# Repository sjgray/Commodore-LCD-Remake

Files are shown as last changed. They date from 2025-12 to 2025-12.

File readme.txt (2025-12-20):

CLCD Re-Make Project  by Steve Gray		cbmsteve.ca
====================  and Mike Naberezny        mikenaberezny.com

The goal of this project is to remake/recreate the never released
Commodore LCD computer. Only a few working prototypes were ever
made. These were almost production ready and luckily a few survived
and information about them was released. Thanks go to Jeff Porter
and Bil Herd for helping with this project. Since the LCD computer
was never produced there are no spare parts and no way to replace
them. Several things are no longer available, such as the custom
chips, keyboard, case and LCD Panel, so we must recreate them or
adapt the design to use modern replacements and similar available parts.

Please see the webpage for more info: http://www.cbmsteve.ca/clcd/index.html

*** This is a work in progress!!! The project is currently incomplete.
    Files are provided for information only. Do not attempt to build
    it unless you are willing to debug and fix things. I will not be
    able to support you. As this is a personal project I can not say
    if or when this might be fully functional!

*** GERBER files have not been provided. They may be made available when
    the project is in a more stable/working state.

DESIGN
======

Schematics
----------

Bil Herd had saved all 4 original pages of the CLCD schematics however
one was misplaced. The 3 pages were sent to Mike, scanned in high-res,
and returned to Bil. Later Bil eventually found the missing page and took
several photos. I (Steve) stitched them together into one photo and used
it as a guide for recreating the missing page.

Design Changes
--------------

Since the custom chips and other parts of the computer were not available
I decided to use a CPLD for the MMU/glue and the C128's VDC chip for the
video. A 32K Dual-port RAM was used for the main memory. Both the CPU and
VDC can access this memory independently/simultaneously and the CPU can
write to it directly without the need to go through the VDC registers. This
means writing to the (text) screen works like the original machine. Only
a small patch is needed for the KERNAL.

Western Design Center still makes 6502-series chips and these were used in
the new design. The original 65C102 CPU was replaced with a 65C02 which is
fully compatible. Similarly equivalent WDC IO chips were also available but
in a smaller PLCC package.

Everything is powered by a simple 12V supply.

LCD Panel/Video
---------------

The original 80x16 (480x128 pixel) monochrome LCD panel was replaced by a
modern widescreen colour panel of roughly the same size. It includes a
controller board with HDMI and composite video inputs. We will use the HDMI
input for best quality. The VDC's RGBI output will be converted to HDMI
using an RGB2HDMI converter. There is an RGBI output connector for an
external display.

Keyboard
--------

Two keyboards were designed with MX switches. One design is like the
original keyboard and uses the diamond arrow cursor. The other design uses
an inverted-T cursor. This design was chosen so that normal keycaps
could be used. Included are files to create custom printed keycaps from
maxkeyboard.com. Custom 3D printed keycaps that match the original, including
the diamond cursor, are in progress for the next revision.

EPROM-PLA
---------

The V1 board initially required the EPROM-PLA board, which plugged into the
expansion connector. This board used an EPROM to emulate a PLA that did
decoding for basic functionality. It is no longer required as it has been
replaced by Mike's CPLD implementation.

Case
----

I have designed a case that can be 3D printed. I used Light-beige PLA.
It must be assembled from multiple pieces and requires brass screw inserts
to hold it together. The initial case is an approximation and has been
designed to accommodate the new LCD panel and it's controller and the
RGB2HDMI adapter. All ports are on the back.

Missing Features
----------------

The battery/power, modem, and barcode port features were not implemented in
the initial design but can hopefully be added later as the design progresses.

V1 PROTO
========

V1 is the first prototype that was developed and demonstrated to Jeff Porter
and Bil Herd.

The first prototype PCB was produced but it requires multiple fixes to
correct errors. These were done by Mike. Mike also did further disassembly of
the CLCD KERNAL to be able to re-assemble it back to an original binary and
then patch it to get the VDC working. He also added serial IO for debug purposes.
Mike wrote the CPLD code that functions like a programmed logic array (PLA) to
map in the 32K RAM, KERNAL ROM and IO. The machine is able to boot.

The MMU has not been implemented yet, so the machine can only boot to the
machine-language monitor at this time. The first prototype PCB was a
proof-of-concept and the ports and placement were not designed to match
the original PCB.

I designed a 3D printed case based on existing prototype photos and some original
documentation, but without any complete measurements. It is split into multiple
pieces for easier printing. It is able to open like the original and uses the
inverted-T keyboard version, colour LCD panel with controller and RGB2HDMI adapter.
All ports are along the back of the computer, and the battery compartment allows
access to the RGB2HDMI adapter's buttons.

When Mike visited Jeff he was able to take detailed photographs and measurements
which will be used for the next version. 

V2 PROTO
========

A V2 design is in the works to correct the errors in the V1 Proto PCB.
Additional work is required for the CPLD to add the MMU functionality that
will allow the machine to run the application ROMS, including the normal
menu system.

As of the initial GitHub commit some fixes have been made but there is more
to do. Routing and parts placement is not complete.

A better keyboard will be designed that will support the low-profile MX
switches and use the replica 3D-designed keycaps.

Future Goals
------------

These are just ideas for future goals.

- Better PCB layout to more match the original pcb
- Better keyboard - Low Profile switches and replica keycaps
- Better case
- MMU support for ROM banking and menu system
- Smaller RGBI to HDMI adapter (current is very tight fit)
- Support for graphics mode.
- Modem support? Perhaps a WIFI solution?
- Internal IEC drive?
- Battery power
- Recreation of custom chips.. not easy
- Disassembly of other built-in apps
- Add support for colour or more screen sizes (40x25, 80x25 etc)
- Replica disk drive (1581 case) and printer (Epson P-80)

Additional Info
---------------

My Facebook group............: https://www.facebook.com/groups/806261867281489
Mike's firmware disassembly..: https://github.com/mnaberez/clcd
Mike's firmware and info page: https://mikenaberezny.com/2008/10/04/commodore-lcd-firmware/
Jeff Porter's LCD prototype..: https://flickr.com/photos/mnaberez/albums/72177720308500331/
Jeff Porter's LCD printer....: https://flickr.com/photos/mnaberez/albums/72177720308512645/
Commodore LCD Emulator Online: http://commodore-lcd.lgb.hu/emulator.html
MAME (Has CLCD emulation)....: https://www.mamedev.org/

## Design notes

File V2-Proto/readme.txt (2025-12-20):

CLCD Re-Make Project by Steve Gray and Mike Naberezny
==================== CBMSTEVE.CA

This folder contains:

PCB/CLCD - V2 work-in-progress. Contains SOME fixes to V1 but not all

Additional folders will be added as the project progresses.

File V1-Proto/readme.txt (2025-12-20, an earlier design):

CLCD Re-Make Project by Steve Gray and Mike Naberezny
==================== CBMSTEVE.CA

This folder contains the V1 prototype files.

The folders are:

3D             - STL files for 3D printed case and keycaps
CPLD           - Source for CPLD decode
Firmware       - Original and new firmware source and build scripts
CherryKeycaps  - SVG files to create custom cherry keycaps from MaxKeyboard.com
PCB            - Kicad design files for CLCD motherboard, EPROM-PLA, and MX Keyboard

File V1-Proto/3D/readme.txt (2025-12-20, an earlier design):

CLCD Re-Make Project by Steve Gray and Mike Naberezny
==================== CBMSTEVE.CA

This folder contains 3D generated STL files that can be printed.
The CASE folder is for the main CLCD case. This must be assembled
from all the different STL files. The Top comes in two pieces and
must be glued or attached with screws. The bottom has areas for
installing brass inserts for mounting the pcb. The TOP has areas
for mounting the LCD controller, backlight board, and RGB2HDMI adapter.
The Display is designed for a 10.25" 60-pin "bar" type LCD panel
(see webpage for details).

The KEYCAPS folder is for replica CLCD keycaps that can be printed
with a resin printer and mounted on standard MX switches.

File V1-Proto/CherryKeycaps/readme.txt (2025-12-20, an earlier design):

CLCD Re-Make Project by Steve Gray and Mike Naberezny
==================== CBMSTEVE.CA

This folder contains SVG files that can be sent to MAXKEYBOARD.COM
to get "Custom Color" Keycaps printed. This contains all the CLCD
keycaps for the Inverted-T MX keyboard and uses MAXKEYBOARD's
104 ANSI set with 6.0U spacebar.

There are two files:
1) Top printing
2) Side (front) printing

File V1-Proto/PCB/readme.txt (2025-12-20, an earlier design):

CLCD Re-Make Project by Steve Gray and Mike Naberezny
==================== CBMSTEVE.CA

This folder contains:

CLCD      - Kicad design files for CLCD Proto V1 which does not work without fixes
KEYBOARD  - Kicad design files for CLCD Keyboard with Inverted-T cursor. Requires one fix
PLA-BOARD - Kicad design files for EPROM PLA Board - no longer required
_FIXES    - Pictures of fixes required to make the V1 Prototype CLCD board functional

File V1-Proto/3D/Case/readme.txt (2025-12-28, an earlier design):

CLCD Case - 3D models in Sketchup and STL formats

## Description			REV	Fill	GRAMS
==============			===	====	=====
 1) Bottom			3	 50	177+++ (w/ back ports, open)
 2) Top Front (keyboard)	2c	100	106
 3) Top Back with tray		8	100	171	(w/ RGB2HDMI/LCD buttons)
 4) Battery cover		4	100 	16
 5) Display Support (x2)	4	 25	8
 6) Screen Front 		6	100	96
 7) Screen Back			6	100	160
 8) Cover Hinges		3	100	1
 9) flipcover    		4	100	76
==============			===	===	=====
Total:						799

Note: + = Not 100% infill, or incomplete (ie: large areas not printed to save PLA)

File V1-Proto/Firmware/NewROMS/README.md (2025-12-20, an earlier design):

# ROMs

This directory contains the ROM code and a script that will generate ready-to-burn images for EPROM sizes 27C010 to 27C080.  Any of these EPROMs can be inserted directly into the EPROM socket on the SteveLCD when the CPLD is used as the address decoder.  When the EPROM-as-PLA board is used, a hardware change on that board is required (see below).

## Building EPROM Images

Run `make` to generate images using the memory map described below.  Each image is a complete system that contains all the original CLCD applications and the KERNAL modified to run on SteveLCD.

```shell
$ make

$ ls *.bin
27c010.bin	27c020.bin	27c040.bin	27c080.bin
```

The 27C020 is the best choice, as described below.

## EPROM Memory Map

Address spaces:

- 6502 address space: 64K: 16 lines: A0-A15
- CLCD physical address space: 256K: 18 lines: A0-A17

32-pin EPROM sizes:
- 27C010 = 128K = A0-A16  
- 27C020 = 256K = A0-A17 ← The 27C020 matches the CLCD so it the best choice.
- 27C040 = 512K = A0-A18  
- 27C080 = 1024K = A0-A19

The SteveLCD board accepts a 32-pin EPROM up to a 27C080.  We store the CLCD firmware in a 27C020.  The 27C020 was chosen because it exactly matches the physical address space of the CLCD, as shown above.  A 27C040 or 27C080 can also used but the extra space will be wasted.  This is not limiting since there is already a huge 128K area free in the 27C020.

The 27C020 needs this memory map to match the CLCD:

- `0x00000-0x1ffff` (128K empty: fill with 0xFF)
- `0x20000-0x27fff` (32K: `ss-calc13apr-u105.bin`)
- `0x28000-0x2ffff` (32K: `sept-M-13apr-u104.bin`)
- `0x30000-0x37fff` (32K: `sizapr-u103.bin`)
- `0x38000-0x3ffff` (32K: `kizapr-u102.bin`)

## EPROM-as-PLA Board Fix

In order to use a 27C020 with the correct CLCD memory map shown above, the EPROM-as-PLA board needed to be reworked.  The EPROM-as-PLA board originally had these hardwired connections:

 - GND → MA16  (A16)
 - GND → MA17  (A17)
 - GND → MA18  (/PGM on 27C020, A18 on 27C040 and 27C080)
 - GND → MA19  (Vpp on 27C020 and 27C040, A19 on 27C080)

The connections were changed to:

 - Vcc → MA16  (A16)
 - Vcc → MA17  (A17)
 - Vcc → MA18  (/PGM on 27C020, A18 on 27C040 and 27C080)
 - Vcc → MA19  (Vpp on 27C020 and 27C040, A19 on 27C080)

The above changes allow any EPROM from 27C010 to 27C080 to be used for the CLCD firmware:

| Pin | 27C010 | 27C020 | 27C040 | 27C080 |
|---|---|---|---|---|
|Pin 2  | A16 | A16 | A16 | A16 |
|Pin 30 | NC | A17 | A17 | A17 |
|Pin 31 | /PGM | /PGM | A18 | A18 |
|Pin 1  | Vpp | Vpp | Vpp | A19 |

27C010:
 - 0x00000-0x1FFFF: CLCD 0x20000-0x3FFFF

27C020:
 - 0x00000-0x3FFFF: CLCD 0x00000-0x3FFFF ← The 27C020 matches the CLCD so it the best choice.

27C040:
 - 0x00000-0x3FFFF: Wasted
 - 0x40000-0x7FFFF: CLCD 0x00000-0x3FFFF

27C080:
 - 0x00000-0xBFFFF: Wasted
 - 0xC0000-0xFFFFF: CLCD 0x00000-0x3FFFF

The 27C010 (128K) can be used since the ROMs from Bil's prototype are only 128K.  However, the lower 128K of the CLCD's 256K address space is lost, so there's no room for expansion.

The 27C020 (256K) is the best choice because its address space exactly matches the CLCD address space.  The upper 128K holds the ROMs dump from Bil Herd's prototype.  The lower 128K is available for new code.

For the 27C040 (512K) and 27C080 (1024K), the CLCD address space is the highest 256K in the EPROM address space.  The rest of the EPROM is inaccessible.

The changes are made at the expansion header on the EPROM-as-PLA board.  MA16 and MA17 are connected to MA18 and MA19 on the bottom side of the board, which in turn connects to GND.  The connection to GND is cut and connected to Vcc instead.

## EPROM Emulator Adapter

The firmware is a 27C020 (256K).  However, my EPROM emulator only emulates up to a 27C256 (32K).  In order to have the built-in applications while being able to program custom KERNALs with my emulator, I built an adapter.  The adapter plugs into the original socket in place of the 27C020.  It has two sockets: one for a 27C020 and one for a 27C256.  The 32K KERNAL area (0x38000-0x3FFFF) goes to the 27C256 so the emulator can be used.  The rest (0x0000-0x37FFFF) goes to the 27C020.

The address lines of the 27C020 are:

 - 27C020 = 256K = A0-17

The EPROM emulator emulates a 27C256.  The address lines of the 27C256 are:

 - 27C256 = 32K = A0-14

The three highest address lines (A15-A17) go to a 74LS138.  It decodes the 256K space of the 27C020 into eight 32K selects.  We use those to select either the 27C020 or the 27C256 on the adapter:

| /CE_ORIGINAL | /LS138_KERNAL_SEL | /CE_27C020 | /CE_27C256 |
|---|---|---|---|
| 0 | 0 | 1  | 0 |
| 0 | 1 | 0  | 1 |
| 1 | 0 | 1  | 1 |
| 1 | 1 | 1  | 1 |

Requirements:
 - `/CE_27C256` is low only when `/CE_ORIGINAL` is low and `/LS138_KERNAL_SEL` is low.
 - `/CE_27C020` is low only when `/CE_ORIGINAL` is low and `/LS138_KERNAL_SEL` is high.

Equations:
 - `/CE_27C256 = /CE_ORIGINAL OR `/LS138_KERNAL_SEL`
 - `/CE_27C020 = /CE_ORIGINAL OR (NOT /LS138_KERNAL_SEL)`

Since only one output of the 74LS138 can be low at any time, we don't need to invert `/LS138_KERNAL_SEL`.  We can just take any other 74LS138 output to simplify the design.

Final Equations:
  - `/CE_27C256 = /CE_ORIGINAL OR /LS138_KERNAL_SEL`
  - `/CE_27C020 = /CE_ORIGINAL OR /LS138_WRONG_SEL`

The "OR" gates are not needed, since the 74LS138 has active low chip selects.  The `/CE_ORIGINAL` signal is fed to /E1 and /E2 on the 74LS138.  Therefore, a single 74LS138 is all that is required.

74LS138 Connections:

 - Pin 16 Vcc
 - Pin 15 /O0 (no connect)
 - Pin 14 /O1 (no connect)
 - Pin 13 /O2 (no connect)
 - Pin 12 /O3 (no connect)
 - Pin 11 /O4 (no connect)
 - Pin 10 /O5 (no connect)
 - Pin 9 /O6 "/LS138_WRONG_SEL" -> /CE_27C020
 - Pin 8 GND
 - Pin 7 /O7 "/LS138_KERNAL_SEL" -> /CE_27C256
 - Pin 6 E3 to Vcc
 - Pin 5 /E2 to /CE_ORIGINAL
 - Pin 4 /E1 to /CE_ORIGINAL
 - Pin 3 A2 to A17
 - Pin 2 A1 to A16
 - Pin 1 A0 to A15

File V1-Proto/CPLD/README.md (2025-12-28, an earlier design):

# Commodore LCD CPLD Decoder

CLCD Re-Make Project by Steve Gray and Mike Naberezny (CBMSTEVE.CA)

MMU implementation by Frank Buss

This folder contains the CPLD code that implements the address decoder and MMU for the Commodore LCD remake.

## MMU Specification Summary

Based on the original 1984 specification documents.

## Overview

The MMU provides address translation for the 65C102 CPU to access up to 256K of physical memory from a 64K logical address space. It supports four modes of operation: KERNEL, APPLICATION, RAM, and TEST.

## Physical Memory Map (18-bit, 256K)

| Address Range | Size | Description |
|---|---|---|
| `$28000`-`$3FFFF` | 96K  | Internal ROM (Kernal & Apps) |
| `$24000`-`$27FFF` | 16K  | Internal Expansion ROM |
| `$20000`-`$23FFF` | 16K  | Wafer Tape I/O Slot |
| `$10000`-`$1FFFF` | 64K  | External Expansion ROM/RAM |
| `$08000`-`$0FFFF` | 32K  | External Expansion RAM |
| `$00000`-`$07FFF` | 32K  | Internal RAM |

## Local (CPU) Memory Map

### Non-Windowed Regions (No Address Translation)

| Address Range | Description |
|---|---|
| `$F800`-`$FFFF` | I/O and MMU Registers |
| `$0000`-`$0FFF` | System RAM (4K, always at `$00000`)  |

### Windowed Regions (Address Translation Applied)

| Window | Address Range | KERNEL Mode | APPL Mode | RAM Mode |
|---|---|---|---|---|
| W1 | `$1000`-`$3FFF` | `$01000`-`$03FFF`  | addr + APPL1 offset | `$01000`-`$03FFF` |
| W2 | `$4000`-`$7FFF` | addr + KERN off | addr + APPL2 offset | `$04000`-`$07FFF` |
| W3 | `$8000`-`$BFFF` | `$38000`-`$3BFFF`  | addr + APPL3 offset | `$08000`-`$0BFFF` |
| W4 | `$C000`-`$F7FF` | `$3C000`-`$3F7FF`  | addr + APPL4 offset | `$0C000`-`$0F7FF` |

## I/O Register Map (`$F800`-`$F9FF`)

| Address Range | Device |
|---|---|
| `$F800`-`$F80F` | VIA #1 |
| `$F880`-`$F88F` | VIA #2 |
| `$F980`-`$F983` | ACIA |

## VDC (LCD Controller) Registers

| Address Range | Device |
|---|---|
| `$FF80`-`$FF83` | VDC (LCD) |

## MMU Control Registers (Write Only)

All registers are 128 bytes apart (`$80`).

### Offset Registers (8-bit value written)

| Address Range | Register |
|---|---|
| `$FF00`-`$FF7F` | KERN Window Offset |
| `$FE80`-`$FEFF` | APPL Window #4 Offset |
| `$FE00`-`$FE7F` | APPL Window #3 Offset |
| `$FD80`-`$FDFF` | APPL Window #2 Offset |
| `$FD00`-`$FD7F` | APPL Window #1 Offset |

### Mode Control (Address-triggered, data ignored)

| Address Range | Function | Implemented |
|---|---|---|
| `$FA00`-`$FA7F` | Set KERNEL Mode | Yes |
| `$FA80`-`$FAFF` | Set APPLICATION Mode | Yes |
| `$FB00`-`$FB7F` | Set RAM Mode | Yes |
| `$FB80`-`$FBFF` | Recall Last Mode | Yes |
| `$FC00`-`$FC7F` | Save Current Mode | Yes |
| `$FC80`-`$FCFF` | Set TEST Mode | No  |

#### SAVE/RECALL Mechanism

The MMU maintains two mode registers:
- **Current mode**: The active operating mode
- **Saved mode**: A backup register for mode switching

**SAVE** (`$FC00`): Copies current mode to saved mode register.
**RECALL** (`$FB80`): Restores saved mode to current mode register.

Typical use case (kernel accessing application memory):
1. Kernel running in KERNEL mode
2. Write to `$FC00` → saves KERNEL mode
3. Write to `$FA80` → switch to APPLICATION mode
4. Access application memory with app's window offsets
5. Write to `$FB80` → RECALL restores KERNEL mode

## Address Translation Algorithm

The physical address is computed by adding an 8-bit offset to the upper 6 bits of the CPU address:

```
CPU Address:    --  --  A15 A14 A13 A12 A11 A10
              +
Offset:         D7  D6  D5  D4  D3  D2  D1  D0
              =
Physical:       S17 S16 S15 S14 S13 S12 S11 S10
```

- A9 through A0 pass through unchanged
- Physical address bits 17:10 = A(15:10) + Offset(7:0)
- This allows mapping any 1K block of CPU space to any 1K block of physical space

## Mode Behavior Summary

### KERNEL Mode
- `$0000`-`$0FFF`: Direct (system RAM)
- `$1000`-`$3FFF`: Direct (`$01000`-`$03FFF`)
- `$4000`-`$7FFF`: Uses KERN offset (windowed)
- `$8000`-`$F7FF`: Fixed to ROM (`$38000`-`$3F7FF`, offset `$C0`)

### APPLICATION Mode
- `$0000`-`$0FFF`: Direct (system RAM)
- `$1000`-`$3FFF`: Uses APPL1 offset (Window 1)
- `$4000`-`$7FFF`: Uses APPL2 offset (Window 2)
- `$8000`-`$BFFF`: Uses APPL3 offset (Window 3)
- `$C000`-`$F7FF`: Uses APPL4 offset (Window 4)

### RAM Mode
- All addresses map directly to physical RAM
- `$0000`-`$0FFF` -> `$00000`-`$00FFF`
- `$1000`-`$3FFF` -> `$01000`-`$03FFF`
- `$4000`-`$7FFF` -> `$04000`-`$07FFF`
- `$8000`-`$BFFF` -> `$08000`-`$0BFFF`
- `$C000`-`$F7FF` -> `$0C000`-`$0F7FF`

## Chip Select Notes

- ROM chip select is only active during reads (rwb='1')
- RAM chip selects are active during phi2='1'
- I/O chip selects are active regardless of phi2
- Internal RAM located in bottom 32K of physical space

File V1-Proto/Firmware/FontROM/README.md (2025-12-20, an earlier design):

# Font ROM

Character sets for the VDC (U17).  Burn into a 27C512.

```text
$ cat 1.bin 2.bin 3.bin 4.bin 5.bin 6.bin 7.bin 8.bin > font1.bin
```

## 1.bin

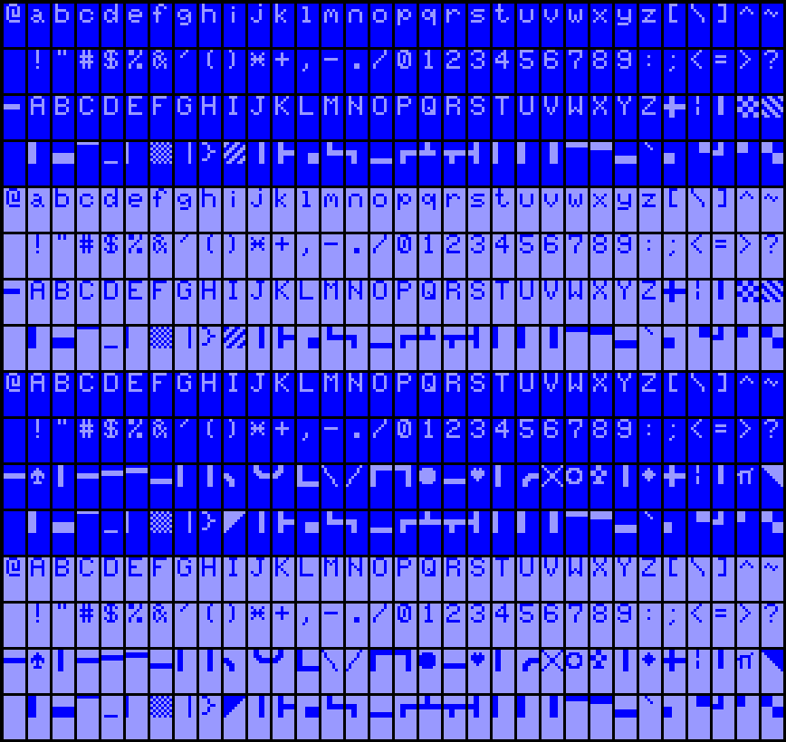
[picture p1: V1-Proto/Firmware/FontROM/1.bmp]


## 2.bin

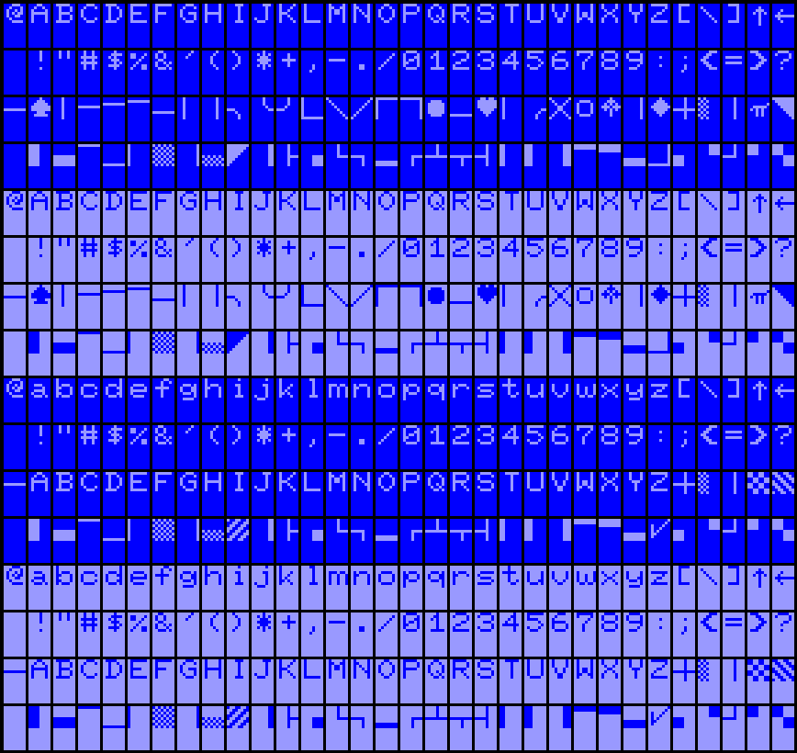
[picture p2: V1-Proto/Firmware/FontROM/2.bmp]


## 3.bin

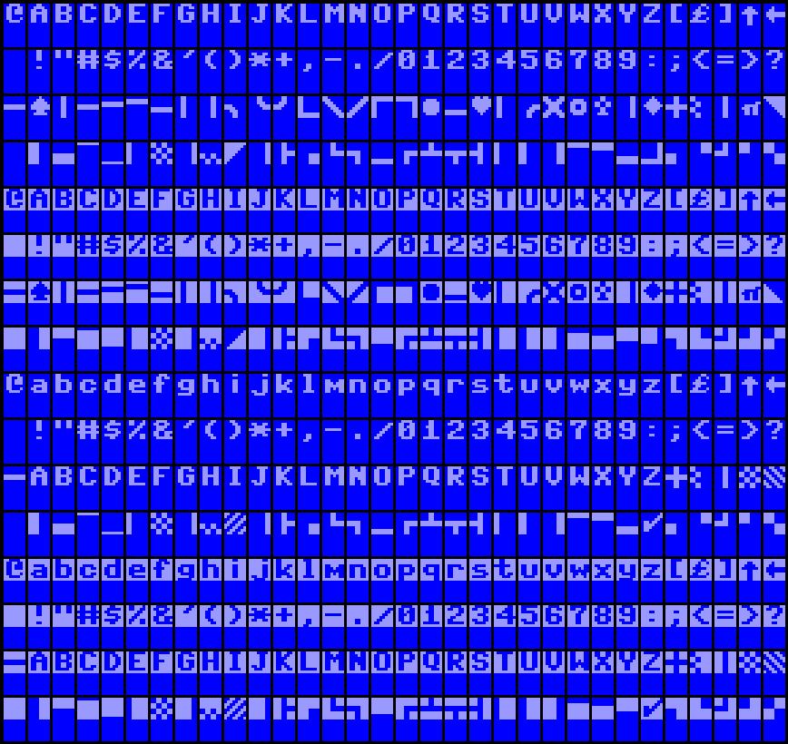
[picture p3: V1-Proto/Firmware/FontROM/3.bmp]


## 4.bin

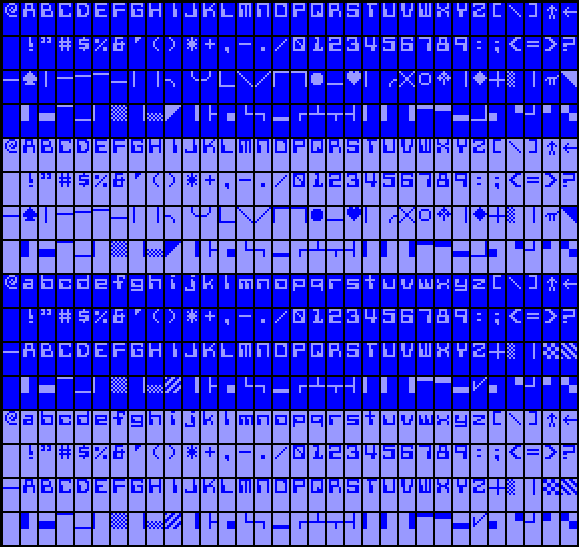
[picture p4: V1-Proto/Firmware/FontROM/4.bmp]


## 5.bin

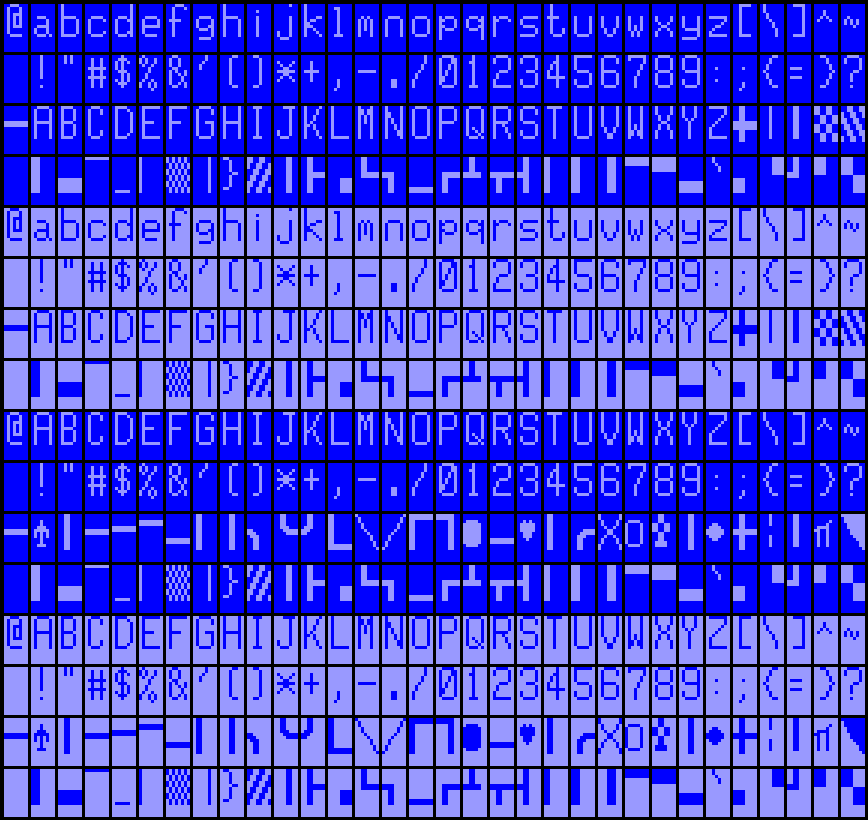
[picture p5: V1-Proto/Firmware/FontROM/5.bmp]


## 6.bin

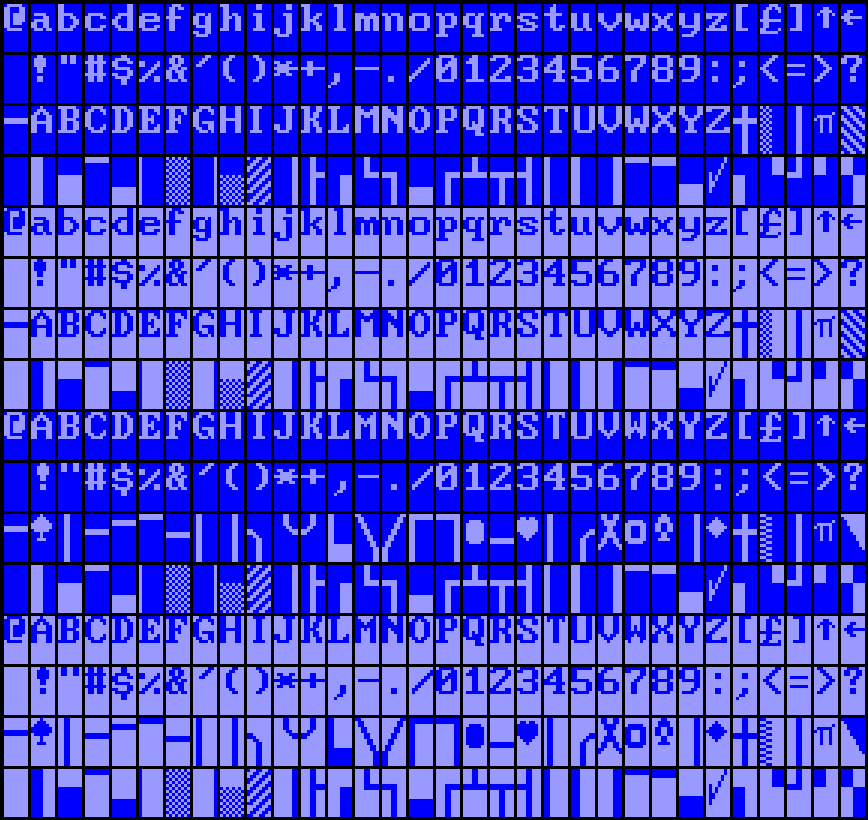
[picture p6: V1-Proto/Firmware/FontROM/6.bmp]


## 7.bin

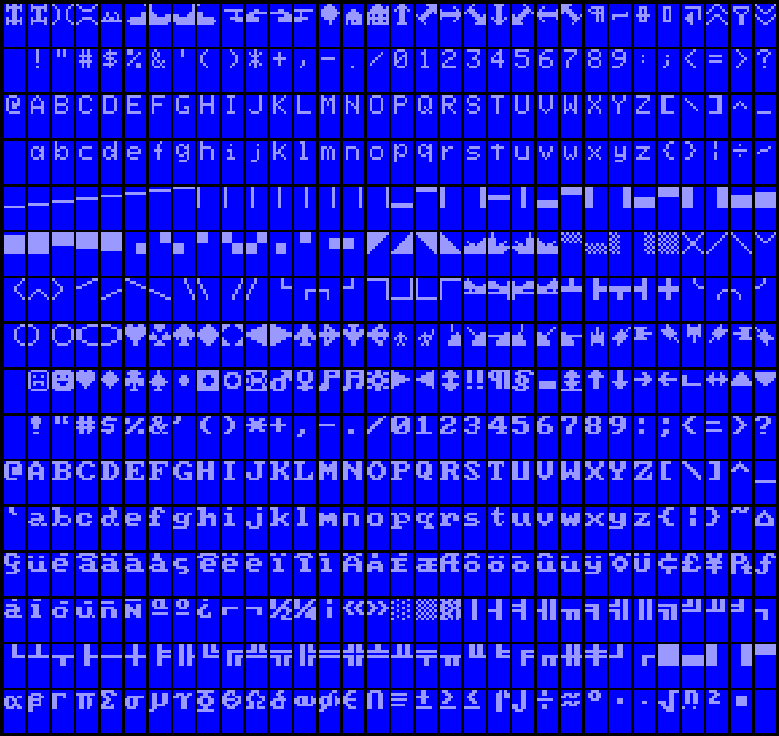
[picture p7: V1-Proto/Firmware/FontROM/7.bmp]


## 8.bin

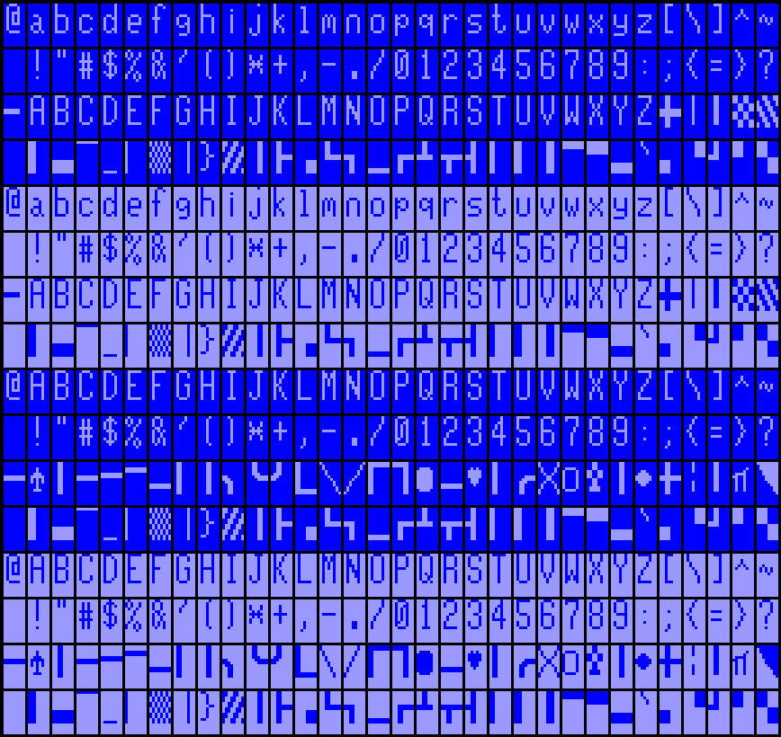
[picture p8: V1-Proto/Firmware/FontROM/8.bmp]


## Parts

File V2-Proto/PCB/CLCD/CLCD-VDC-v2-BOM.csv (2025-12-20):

Source: | K:\Personal\Steve\KiCadProjects\CLCD\CLCD-VDC.kicad_sch
Date: | 2022-07-02 11:38:55 AM
Tool: | Eeschema (6.0.2)
Generator: | C:\Program Files\KiCad\6.0\bin\scripting\plugins/bom_csv_grouped_by_value_with_fp.py
Component Count: | 100
Ref | Qnty | Value | Cmp name | Footprint | Description | Vendor
C1, C2, C3, C4, | 4 | 22pF | C-superpet-rescue | Capacitor_THT:C_Disc_D4.7mm_W2.5mm_P5.00mm
C5, C6, C7, C8, | 4 | 1uF | C_Polarized_US | Capacitor_THT:C_Disc_D4.7mm_W2.5mm_P5.00mm | Polarized capacitor, US symbol
C9, C10, C11, C12, C13, C14, C15, C16, C17, C20, C21, C22, C23, C27, | 14 | 0.1 | C_Small | Capacitor_THT:C_Disc_D4.7mm_W2.5mm_P5.00mm | Unpolarized capacitor, small symbol
C18, | 1 | C_Polarized | C_Polarized | Capacitor_THT:CP_Radial_D7.5mm_P2.50mm | Polarized capacitor
C28, | 1 | 0.01uf * | C_Small | Capacitor_THT:C_Disc_D4.7mm_W2.5mm_P5.00mm | Unpolarized capacitor, small symbol
CN1, | 1 | SERIAL_BUS_CON | SERIAL_BUS_CON | KU-14194HB-RevB-KiCad:SERIAL_CON_DIN6
J1, | 1 | JTAG | Conn_02x05_Odd_Even-superpet-rescue | Connector_PinHeader_2.54mm:PinHeader_2x05_P2.54mm_Vertical
J2, J3, J4, J6, | 4 | Conn_01x08 | Conn_01x08 | Connector_PinHeader_2.54mm:PinHeader_1x08_P2.54mm_Vertical | Generic connector, single row, 01x08, script generated (kicad-library-utils/schlib/autogen/connector/)
J5, | 1 | IDC Header | Conn_02x13_Counter_Clockwise | Connector_PinHeader_2.54mm:PinHeader_2x13_P2.54mm_Vertical | Generic connector, double row, 02x13, counter clockwise pin numbering scheme (similar to DIP packge numbering), script generated (kicad-library-utils/schlib/autogen/connector/)
J7, | 1 | DB25_Male_MountingHoles | DB25_Male_MountingHoles | Connector_Dsub:DSUB-25_Male_Horizontal_P2.77x2.84mm_EdgePinOffset4.94mm_Housed_MountingHolesOffset7.48mm | 25-pin male D-SUB connector, Mounting Hole
J8, | 1 | VDC_FONTOPT | Conn_01x03 | Connector_PinHeader_2.54mm:PinHeader_1x03_P2.54mm_Vertical | Generic connector, single row, 01x03, script generated (kicad-library-utils/schlib/autogen/connector/)
J9, | 1 | Centronics Header | Conn_01x12 | Connector_PinHeader_2.54mm:PinHeader_1x12_P2.54mm_Vertical | Generic connector, single row, 01x12, script generated (kicad-library-utils/schlib/autogen/connector/)
J10, J26, | 2 | POWER | Conn_01x02 | Connector_PinHeader_2.54mm:PinHeader_1x02_P2.54mm_Vertical | Generic connector, single row, 01x02, script generated (kicad-library-utils/schlib/autogen/connector/)
J11, | 1 | IEC Header | Conn_01x06 | Connector_PinHeader_2.54mm:PinHeader_1x06_P2.54mm_Vertical | Generic connector, single row, 01x06, script generated (kicad-library-utils/schlib/autogen/connector/)
J12, | 1 | Barrel_Jack_Switch | Barrel_Jack_Switch | Connector_BarrelJack:BarrelJack_Horizontal | DC Barrel Jack with an internal switch
J13, | 1 | CS_Header | Conn_01x07 | Connector_PinHeader_2.54mm:PinHeader_1x07_P2.54mm_Vertical | Generic connector, single row, 01x07, script generated (kicad-library-utils/schlib/autogen/connector/)
J14, | 1 | Barcode Header | Conn_01x03 | Connector_PinHeader_2.54mm:PinHeader_1x03_P2.54mm_Vertical | Generic connector, single row, 01x03, script generated (kicad-library-utils/schlib/autogen/connector/)
J15, | 1 | PIEZO ENABLE | Conn_01x02 | Connector_PinHeader_2.54mm:PinHeader_1x02_P2.54mm_Vertical | Generic connector, single row, 01x02, script generated (kicad-library-utils/schlib/autogen/connector/)
J16, | 1 | TTL SERIAL | Conn_01x04 | Connector_PinHeader_2.54mm:PinHeader_1x04_P2.54mm_Vertical | Generic connector, single row, 01x04, script generated (kicad-library-utils/schlib/autogen/connector/)
J17, | 1 | DB9_Male_MountingHoles | DB9_Male_MountingHoles-superpet-rescue | Connector_Dsub:DSUB-9_Male_Horizontal_P2.77x2.84mm_EdgePinOffset4.94mm_Housed_MountingHolesOffset7.48mm
J18, | 1 | RS232 Header | Conn_02x05_Odd_Even | Connector_PinHeader_2.54mm:PinHeader_2x05_P2.54mm_Vertical | Generic connector, double row, 02x05, odd/even pin numbering scheme (row 1 odd numbers, row 2 even numbers), script generated (kicad-library-utils/schlib/autogen/connector/)
J19, | 1 | RGBI | Conn_01x10 | Connector_PinHeader_2.54mm:PinHeader_1x10_P2.54mm_Vertical | Generic connector, single row, 01x10, script generated (kicad-library-utils/schlib/autogen/connector/)
J20, | 1 | DB9_Female | DB9_Female | Connector_Dsub:DSUB-9_Female_Horizontal_P2.77x2.84mm_EdgePinOffset4.94mm_Housed_MountingHolesOffset7.48mm | 9-pin female D-SUB connector
J21, | 1 | VDC_A14 | Conn_01x03 | Connector_PinHeader_2.54mm:PinHeader_1x03_P2.54mm_Vertical | Generic connector, single row, 01x03, script generated (kicad-library-utils/schlib/autogen/connector/)
J22, | 1 | RESET | Conn_01x03 | Connector_PinHeader_2.54mm:PinHeader_1x03_P2.54mm_Vertical | Generic connector, single row, 01x03, script generated (kicad-library-utils/schlib/autogen/connector/)
J23, J25, | 2 | Conn_01x01 | Conn_01x01 | Connector_PinHeader_2.54mm:PinHeader_1x01_P2.54mm_Vertical | Generic connector, single row, 01x01, script generated (kicad-library-utils/schlib/autogen/connector/)
J24, | 1 | CPU Clock | Conn_02x04_Odd_Even | Connector_PinHeader_2.54mm:PinHeader_2x04_P2.54mm_Vertical | Generic connector, double row, 02x04, odd/even pin numbering scheme (row 1 odd numbers, row 2 even numbers), script generated (kicad-library-utils/schlib/autogen/connector/)
J28, | 1 | Conn_02x25_Counter_Clockwise | Conn_02x25_Counter_Clockwise | Connector_PinHeader_2.54mm:PinHeader_2x25_P2.54mm_Vertical | Generic connector, double row, 02x25, counter clockwise pin numbering scheme (similar to DIP packge numbering), script generated (kicad-library-utils/schlib/autogen/connector/)
J31, | 1 | VDC UPSEL | Conn_01x03 | Connector_PinHeader_2.54mm:PinHeader_1x03_P2.54mm_Vertical | Generic connector, single row, 01x03, script generated (kicad-library-utils/schlib/autogen/connector/)
J32, | 1 | VDC Clock | Conn_02x04_Odd_Even | Connector_PinHeader_2.54mm:PinHeader_2x04_P2.54mm_Vertical | Generic connector, double row, 02x04, odd/even pin numbering scheme (row 1 odd numbers, row 2 even numbers), script generated (kicad-library-utils/schlib/autogen/connector/)
MT1, | 1 | Piezo | Speaker | TestPoint:TestPoint_2Pads_Pitch2.54mm_Drill0.8mm | Speaker
Q1, Q2, Q3, Q4, Q5, | 5 | 2N3904 | 2N3904 | Package_TO_SOT_THT:TO-92_Inline | 0.2A Ic, 40V Vce, Small Signal NPN Transistor, TO-92
R1, R5, R7, | 3 | 1K | R | Resistor_THT:R_Axial_DIN0204_L3.6mm_D1.6mm_P7.62mm_Horizontal | Resistor
R2, R3, R4, R6, R8, | 5 | 4K7 | R | Resistor_THT:R_Axial_DIN0204_L3.6mm_D1.6mm_P7.62mm_Horizontal | Resistor
R9, | 1 | 100K | R | Resistor_THT:R_Axial_DIN0204_L3.6mm_D1.6mm_P7.62mm_Horizontal | Resistor
R10, | 1 | 10K | R | Resistor_THT:R_Axial_DIN0204_L3.6mm_D1.6mm_P7.62mm_Horizontal | Resistor
RN1, RN2, | 2 | 10K | R_Network08_US | Resistor_THT:R_Array_SIP9 | 8 resistor network, star topology, bussed resistors, small US symbol
RN3, | 1 | CPU pullups | R_Network04 | Resistor_THT:R_Array_SIP5 | 4 resistor network, star topology, bussed resistors, small symbol
SW1, | 1 | RESET | SW_Push | Button_Switch_THT:SW_Tactile_SPST_Angled_PTS645Vx58-2LFS | Push button switch, generic, two pins
SW2, | 1 | SW_DPST | SW_DPST | Button_Switch_THT:SW_Push_2P1T_Toggle_CK_PVA1xxH2xxxxxxV2 | Double Pole Single Throw (DPST) Switch
U1, | 1 | 74HC14 | 74HC14 | Package_DIP:DIP-14_W7.62mm_LongPads | Hex inverter schmitt trigger
U2, U3, | 2 | 74HC165 | 74HC165 | Package_DIP:DIP-16_W7.62mm_LongPads | Shift Register, 8-bit, Parallel Load
U5, | 1 | HM628512A | HM628512A-superpet-rescue | Package_DIP:DIP-32_W15.24mm_LongPads
U6, U13, | 2 | W65C22NxPL | W65C22NxPL | Package_LCC:PLCC-44_THT-Socket | W65C22N CMOS Versatile Interface Adapter (VIA), 20-pin I/O, 2 Timer/Counters, NMOS-Compatible, PLCC-44
U7, | 1 | W65C02SxPL | W65C02SxPL | Package_LCC:PLCC-44_THT-Socket | W65C02S 8-bit CMOS General Purpose Microprocessor, PLCC-44
U8, | 1 | 74LS393 | 74LS393 | Package_DIP:DIP-14_W7.62mm_LongPads | Dual BCD 4-bit counter
U9, | 1 | EPM7128S | EPM7128S-superpet-rescue | Package_LCC:PLCC-84_THT-Socket
U10, | 1 | 74HC374 | 74HC374 | Package_DIP:DIP-20_W7.62mm_LongPads | 8-bit Register, 3-state outputs
U11, | 1 | 27C080 | 27C080 | Package_DIP:DIP-32_W15.24mm_LongPads | OTP EPROM 8 MiBit (1 Mi x 8)
U14, | 1 | msm58321 | msm58321 | Package_DIP:DIP-16_W7.62mm_LongPads | Realtime Clock
U15, | 1 | 74LS573 | 74LS573 | Package_DIP:DIP-20_W7.62mm_LongPads | 8-bit Latch 3-state outputs
U16, | 1 | 74LS244 | 74LS244 | Package_DIP:DIP-20_W7.62mm_LongPads | Octal Buffer and Line Driver With 3-State Output, active-low enables, non-inverting outputs
U17, | 1 | 27C512 | 27C512 | Package_DIP:DIP-28_W15.24mm_LongPads
U18, | 1 | 8563 | 8563 | Package_DIP:DIP-48_W15.24mm_LongPads
U19, | 1 | 6551 | 6551-superpet-rescue | Package_DIP:DIP-28_W15.24mm_LongPads
U20, | 1 | IDT7007PLCC | IDT7007PLCC | Package_LCC:PLCC-68_THT-Socket
U21, | 1 | MAX238 | MAX238 | Package_DIP:DIP-24_W7.62mm_LongPads
U22, | 1 | 74LS04 | 74LS04 | Package_DIP:DIP-14_W7.62mm_LongPads | Hex Inverter
U23, | 1 | UM61512A | UM61512A | Package_DIP:DIP-32_W7.62mm
X1, X10, | 2 | CXO_DIP8 | CXO_DIP8 | Oscillator:Oscillator_DIP-8 | Crystal Clock Oscillator, DIP8-style metal package
X2, | 1 | 32.768kHz, HC49U | Crystal-superpet-rescue | Crystal:Crystal_HC49-U_Vertical
X3, | 1 | 1.8432 MHz, HC49U | Crystal-superpet-rescue | Crystal:Crystal_HC49-U_Vertical

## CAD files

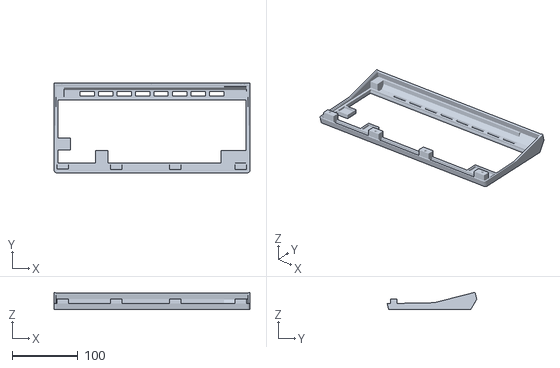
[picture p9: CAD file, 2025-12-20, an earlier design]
V1-Proto/3D/Case/STL/top-front-rev2c.stl
299.0 x 136.8 x 26.6

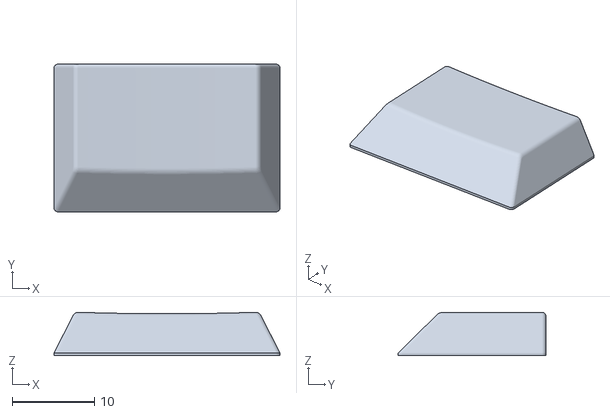
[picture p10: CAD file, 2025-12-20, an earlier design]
V1-Proto/3D/Keycaps/clcd-1.5u-rev1.stl
27.5 x 18.0 x 5.28

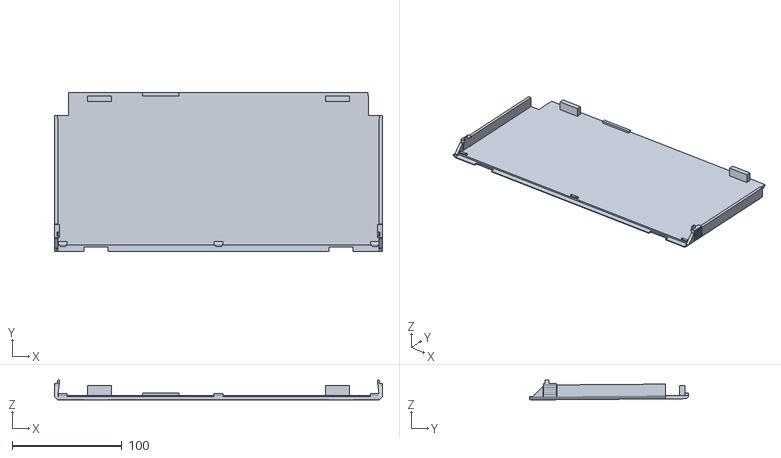
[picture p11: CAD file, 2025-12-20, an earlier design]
V1-Proto/3D/Case/STL/screen-back-rev7.stl
299.0 x 145.0 x 18.1

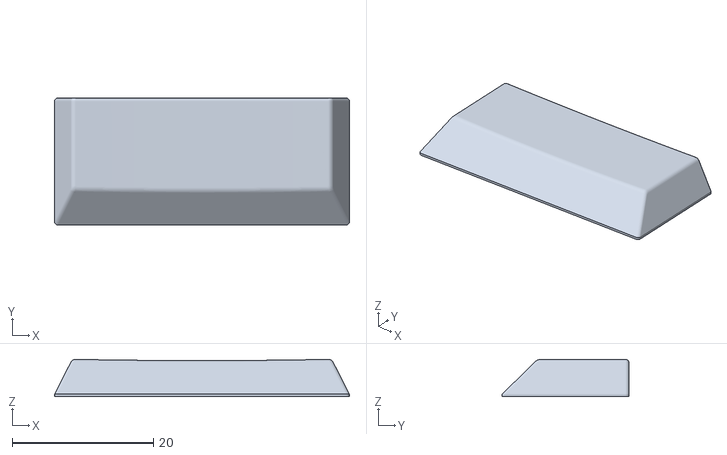
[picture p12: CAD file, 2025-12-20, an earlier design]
V1-Proto/3D/Keycaps/clcd-2.25u-rev1.stl
41.8 x 18.0 x 5.28

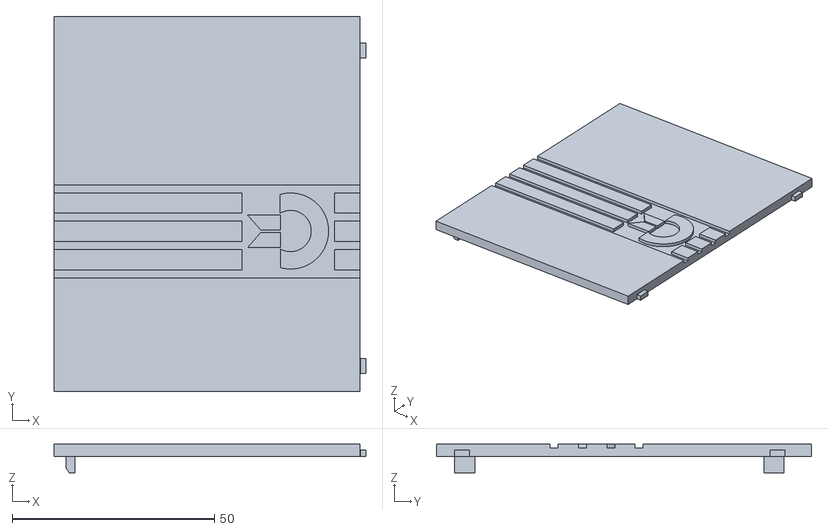
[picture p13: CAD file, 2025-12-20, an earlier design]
V1-Proto/3D/Case/STL/batterycover-rev4.stl
77.1 x 92.6 x 7.10

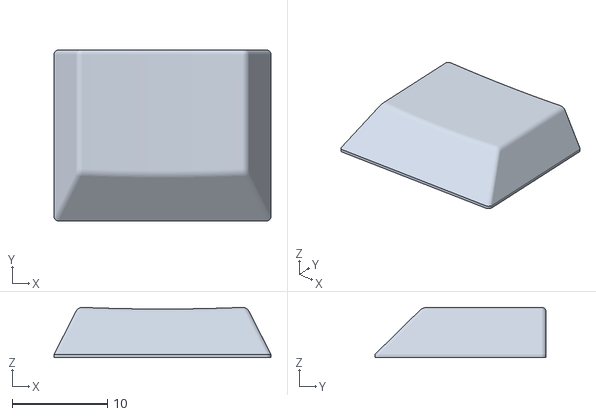
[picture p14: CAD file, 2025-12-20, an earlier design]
V1-Proto/3D/Keycaps/clcd-1.25u-rev1.stl
22.8 x 18.0 x 5.28

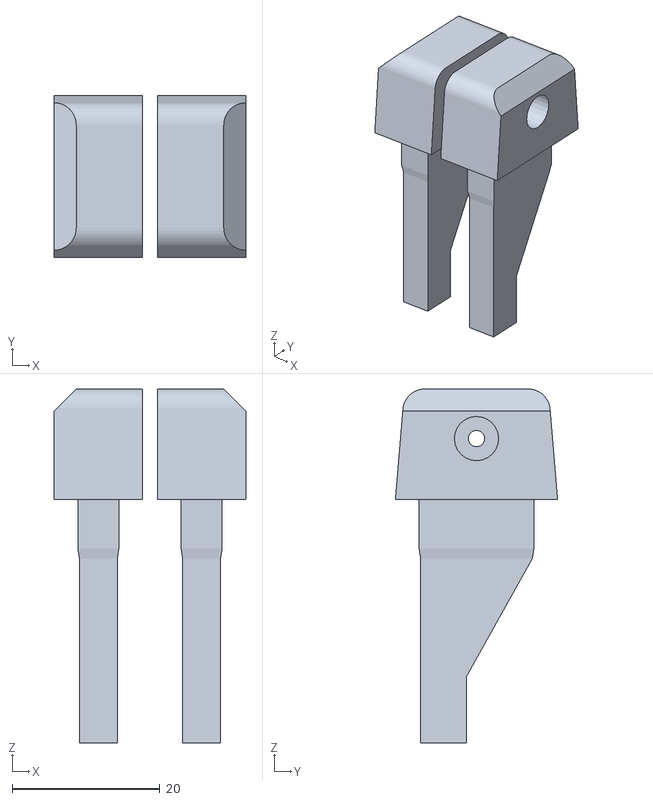
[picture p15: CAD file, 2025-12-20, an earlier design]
V1-Proto/3D/Case/STL/display-support-ver4.stl
26.0 x 22.0 x 48.0

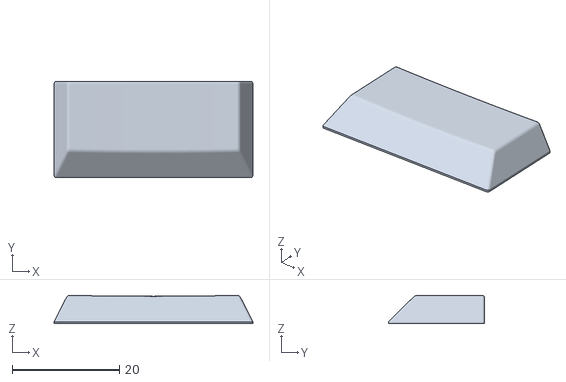
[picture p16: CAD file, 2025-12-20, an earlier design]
V1-Proto/3D/Keycaps/clcd-2.00u-rev1.stl
37.1 x 18.0 x 5.28

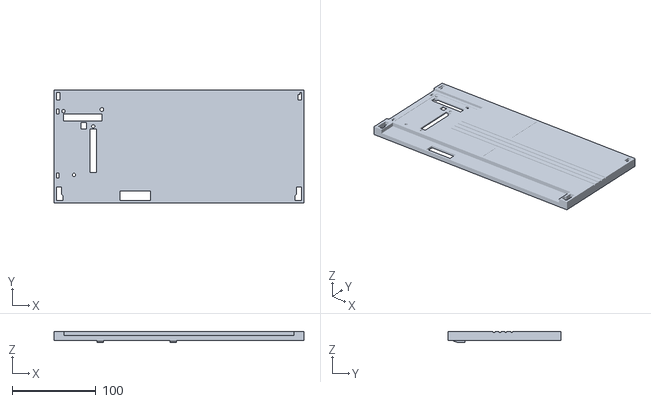
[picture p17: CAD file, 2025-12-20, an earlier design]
V1-Proto/3D/Case/STL/top-back-rev8.stl
299.0 x 135.0 x 13.1

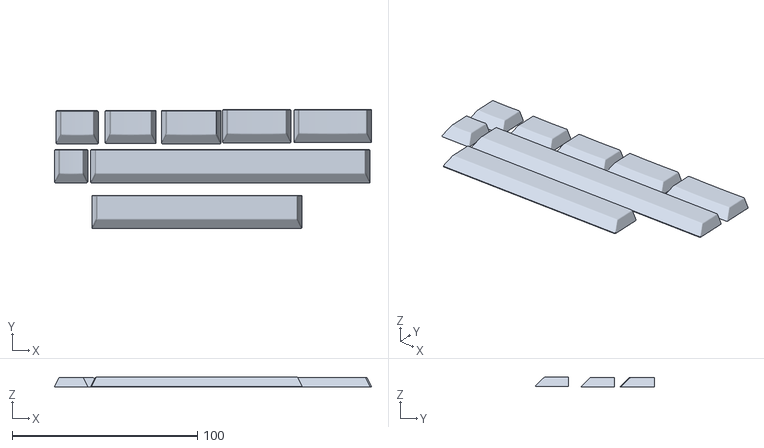
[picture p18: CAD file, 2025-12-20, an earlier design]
V1-Proto/3D/Keycaps/clcd-all-sizes.stl
171.3 x 64.4 x 5.66

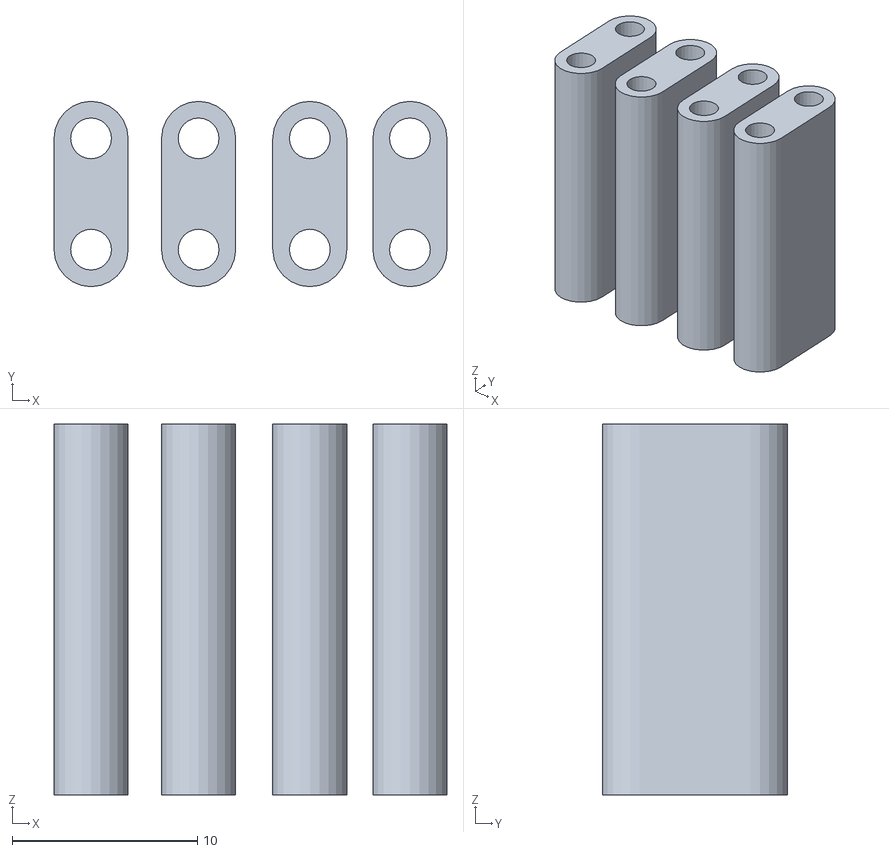
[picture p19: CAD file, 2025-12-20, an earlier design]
V1-Proto/3D/Case/STL/coverhinge-rev3.stl
21.2 x 10.00 x 20.0

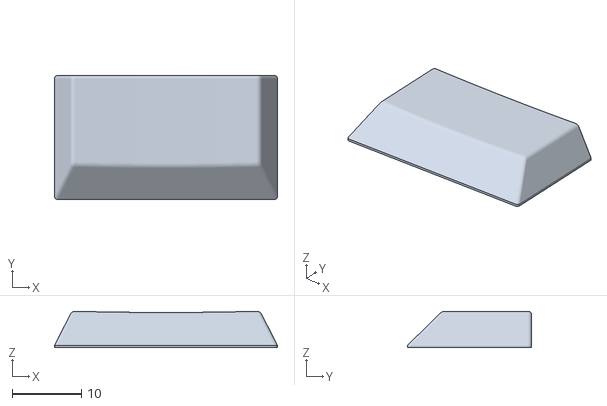
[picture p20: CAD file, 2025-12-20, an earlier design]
V1-Proto/3D/Keycaps/clcd-1.75u-rev1.stl
32.3 x 18.0 x 5.28

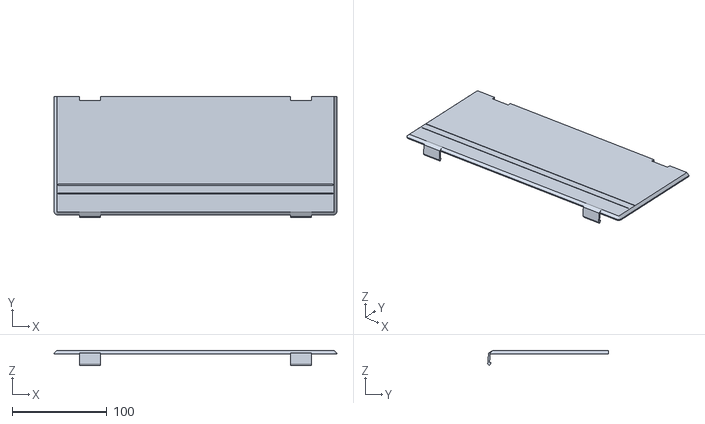
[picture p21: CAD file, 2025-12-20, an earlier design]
V1-Proto/3D/Case/STL/flipcover-rev4.stl
299.0 x 127.4 x 15.9

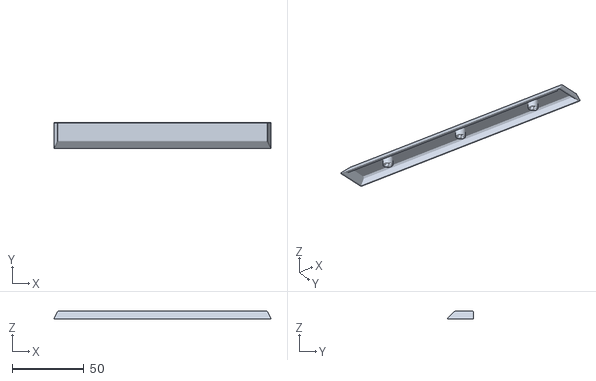
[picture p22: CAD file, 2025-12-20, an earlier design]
V1-Proto/3D/Keycaps/clcd-8u-rev1.stl
151.0 x 18.0 x 5.28

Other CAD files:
V1-Proto/3D/Case/STL/bottom-rev3.stl
V1-Proto/3D/Keycaps/clcd-6u-rev1.stl
V1-Proto/3D/Case/STL/screen-front-rev8.stl
V1-Proto/3D/Keycaps/clcd-1u-rev1.stl
V1-Proto/3D/Case/Sketchup/CLCD-case-rev1 full.skp
V1-Proto/3D/Case/Sketchup/Full model.skp
V1-Proto/3D/Case/Sketchup/batterycover-rev3.skp
V1-Proto/3D/Case/Sketchup/batterycover-rev4.skp
V1-Proto/3D/Case/Sketchup/batterytray-rev3.skp
V1-Proto/3D/Case/Sketchup/bottom-rev3.skp
V1-Proto/3D/Case/Sketchup/coverhinge-rev3.skp
V1-Proto/3D/Case/Sketchup/display-support-ver4.skp
V1-Proto/3D/Case/Sketchup/flipcover-rev3.skp
V1-Proto/3D/Case/Sketchup/flipcover-rev4.skp
V1-Proto/3D/Case/Sketchup/keyboard-sk-both-rev1.skp
V1-Proto/3D/Case/Sketchup/keyboard-sk-bottom-rev1.skp
V1-Proto/3D/Case/Sketchup/screen-back-rev7.skp
V1-Proto/3D/Case/Sketchup/screen-combo-temp.skp
V1-Proto/3D/Case/Sketchup/screen-front-rev8.skp
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

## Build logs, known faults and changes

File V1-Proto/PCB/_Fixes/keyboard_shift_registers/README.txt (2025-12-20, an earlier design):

This graphic is the Commodore LCD schematic but the markup in 
blue shows the correct connections for SteveLCD.

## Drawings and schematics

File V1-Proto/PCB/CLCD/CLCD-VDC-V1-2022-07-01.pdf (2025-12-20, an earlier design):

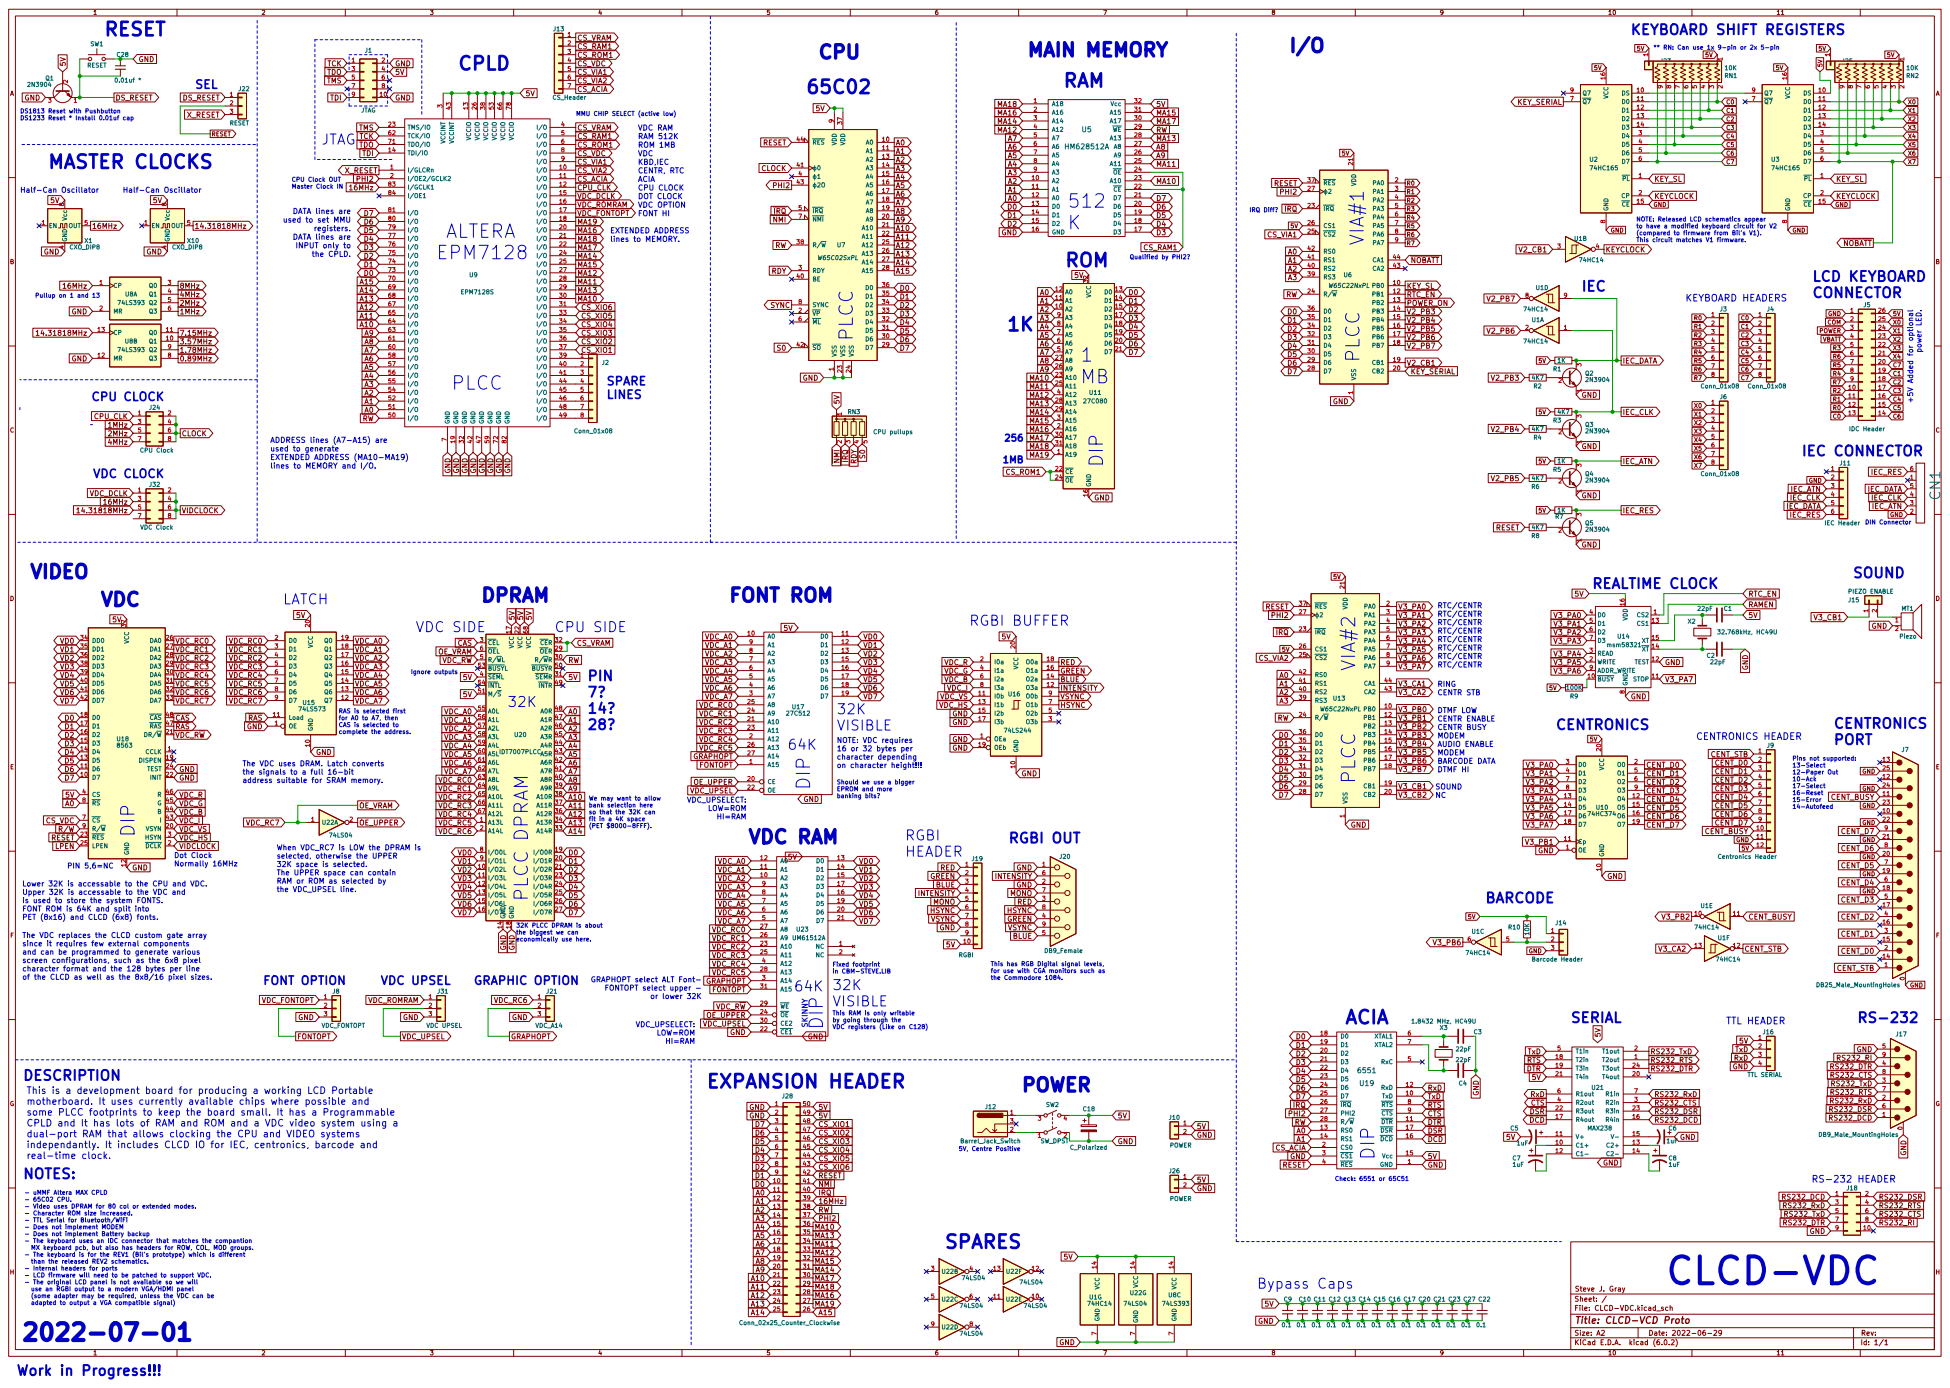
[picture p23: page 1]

(compared to firmware from Bil's V1). This circuit matches V1 firmware. RESET
J13 CS_Header C28

** RN: Can use 1x 9-pin or 2x 5-pin
J23 Conn_01x01 ~{PL} 1 DS

DS1813 Reset with Pushbutton DS1233 Reset * Install 0.01uf cap

1 A0 10 A1 11 A2 13 A3 14 A4 15 A5 16 A6 17 A7 18 A8 19 ~{VP} 2 A9 20 A10 21 A11 22 VSS 23 VSS 24 A12 25 A13 26 A14 27 A15 28 D7 29 RDY 3 D6 30 D5 31 D4 32 D3 33 D2 34 D1 35 D0 36 VDD 37
~{IRQ} PHI2 S0 RDY

Pins not supported: 13-Select 12-Paper Out 10-Ack 17-Select 16-Reset 15-Error 14-Autofeed VIA#1 PLCC

CPU Clock OUT Master Clock IN DATA lines are

used to set MMU
registers.
DATA lines are
INPUT only to
the CPLD.

NOTE: Released LCD schematics appear
to have a modified keyboard circuit for V2

5 RN3 CPU pullups EN 1 GND

SOUND +5V Added for optional power LED. DIP

ADDRESS lines (A7-A15) are
used to generate
EXTENDED ADDRESS (MA10-MA19)
lines to MEMORY and I/O.

RAS is selected first
for A0 to A7, then CAS is selected to

The VDC uses DRAM. Latch converts
the signals to a full 16-bit
address suitable for SRAM memory.

VDC_A7 A13 A12 A10 A9A11
We may want to allow
bank selection here
so that the 32K can
fit in a 4K space

Should we use a bigger EPROM and more

When VDC_RC7 is LOW the DPRAM is
selected, otherwise the UPPER
32K space is selected.
The UPPER space can contain
RAM or ROM as selected by
VD5 FONTOPT

Lower 32K is accessable to the CPU and VDC.
Upper 32K is accessable to the VDC and
is used to store the system FONTS.
FONT ROM is 64K and split into
PET (8x16) and CLCD (6x8) fonts.

32K PLCC DPRAM is about
the biggest we can
economically use here.

The VDC replaces the CLCD custom gate array
since it requires few external components
and can be programmed to generate various
screen configurations, such as the 6x8 pixel
character format and the 128 bytes per line
of the CLCD as well as the 8x8/16 pixel sizes.

in CBM-STEVE.LIB EXPANSION HEADER
VDC_RC5
GRAPHOPT
FONTOPT

This has RGB Digital signal levels,
for use with CGA monitors such as

GRAPHOPT select ALT Font-
FONTOPT select upper - or lower 32K

This RAM is only writable

DESCRIPTION
This is a development board for producing a working LCD Portable
motherboard. It uses currently available chips where possible and
some PLCC footprints to keep the board small. It has a Programmable
CPLD and It has lots of RAM and ROM and a VDC video system using a
dual-port RAM that allows clocking the CPU and VIDEO systems
independantly. It includes CLCD IO for IEC, centronics, barcode and
real-time clock.

- uMMF Altera MAX CPLD
- 65C02 CPU. - Video uses DPRAM for 80 col or extended modes. - Character ROM size increased. - TTL Serial for Bluetooth/WiFi - Does not implement MODEM

- Does not implement Battery backup
- The keyboard uses an IDC connector that matches the compantion
MX keyboard pcb, but also has headers for ROW, COL, MOD groups.
- The keyboard is for the REV1 (Bil's prototype) which is different
than the released REV2 schematics. - Internal headers for ports
- LCD firmware will need to be patched to support VDC.
- The original LCD panel is not available so we will
use an RGBI output to a modern VGA/HDMI panel
(some adapter may be required, unless the VDC can be

File: CLCD-VDC.kicad_sch Sheet: / Steve J. Gray

adapted to output a VGA compatible signal)

Id: 1/1 Title: CLCD-VCD Proto

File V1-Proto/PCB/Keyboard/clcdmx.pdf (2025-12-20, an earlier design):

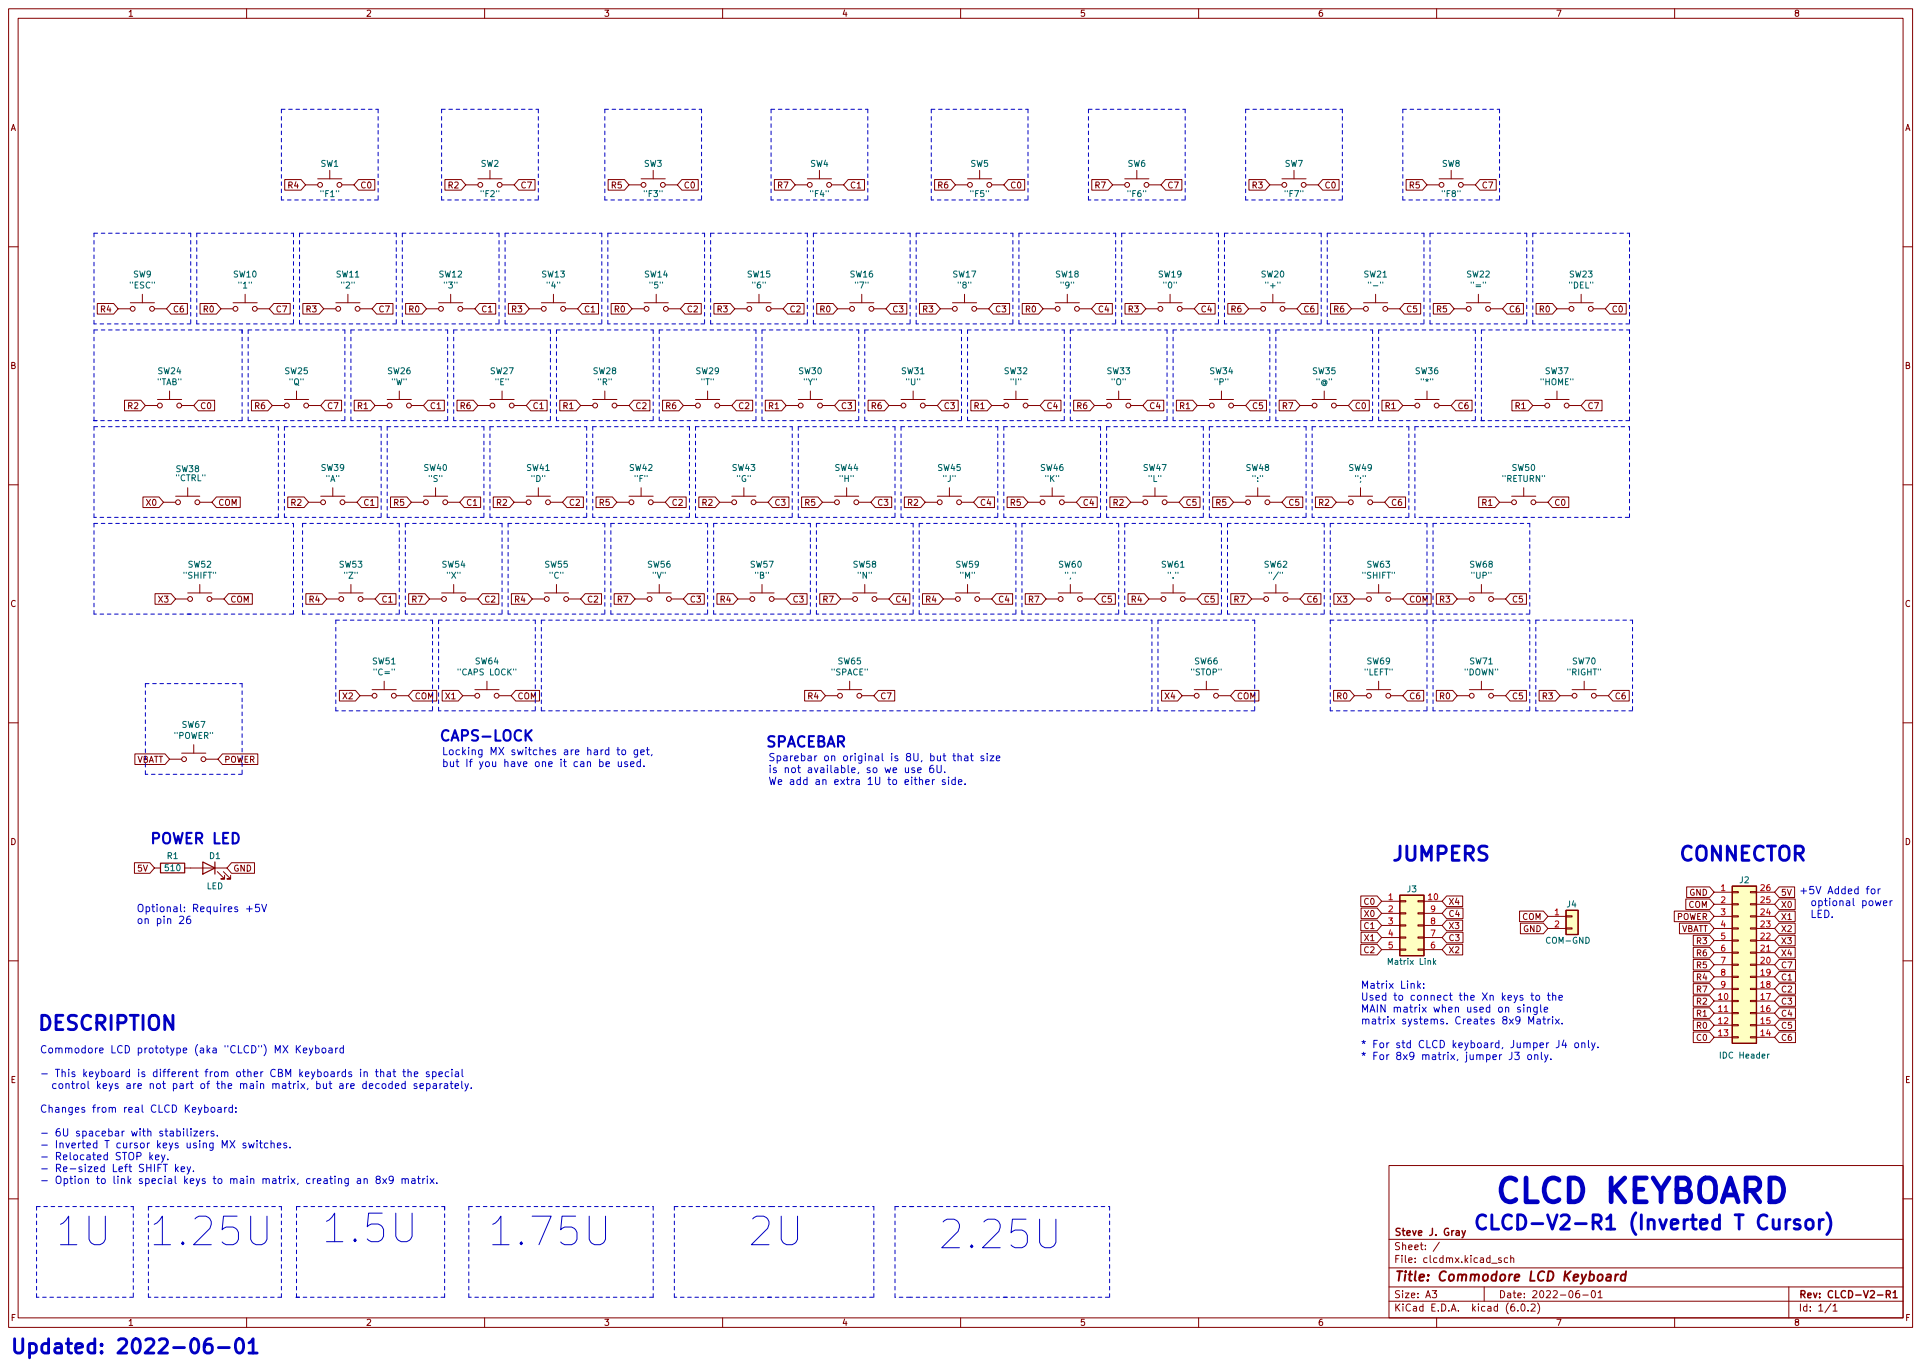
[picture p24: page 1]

Locking MX switches are hard to get,
but If you have one it can be used.

Sparebar on original is 8U, but that size
is not available, so we use 6U.
We add an extra 1U to either side.

Matrix Link: Used to connect the Xn keys to the

MAIN matrix when used on single
matrix systems. Creates 8x9 Matrix.

* For std CLCD keyboard, Jumper J4 only.
* For 8x9 matrix, jumper J3 only.

Commodore LCD prototype (aka "CLCD") MX Keyboard

- This keyboard is different from other CBM keyboards in that the special
control keys are not part of the main matrix, but are decoded separately.

Changes from real CLCD Keyboard:

- 6U spacebar with stabilizers.
- Inverted T cursor keys using MX switches.
- Relocated STOP key.
- Re-sized Left SHIFT key.
- Option to link special keys to main matrix, creating an 8x9 matrix.

File: clcdmx.kicad_sch Sheet: / Steve J. Gray

Id: 1/1 Title: Commodore LCD Keyboard

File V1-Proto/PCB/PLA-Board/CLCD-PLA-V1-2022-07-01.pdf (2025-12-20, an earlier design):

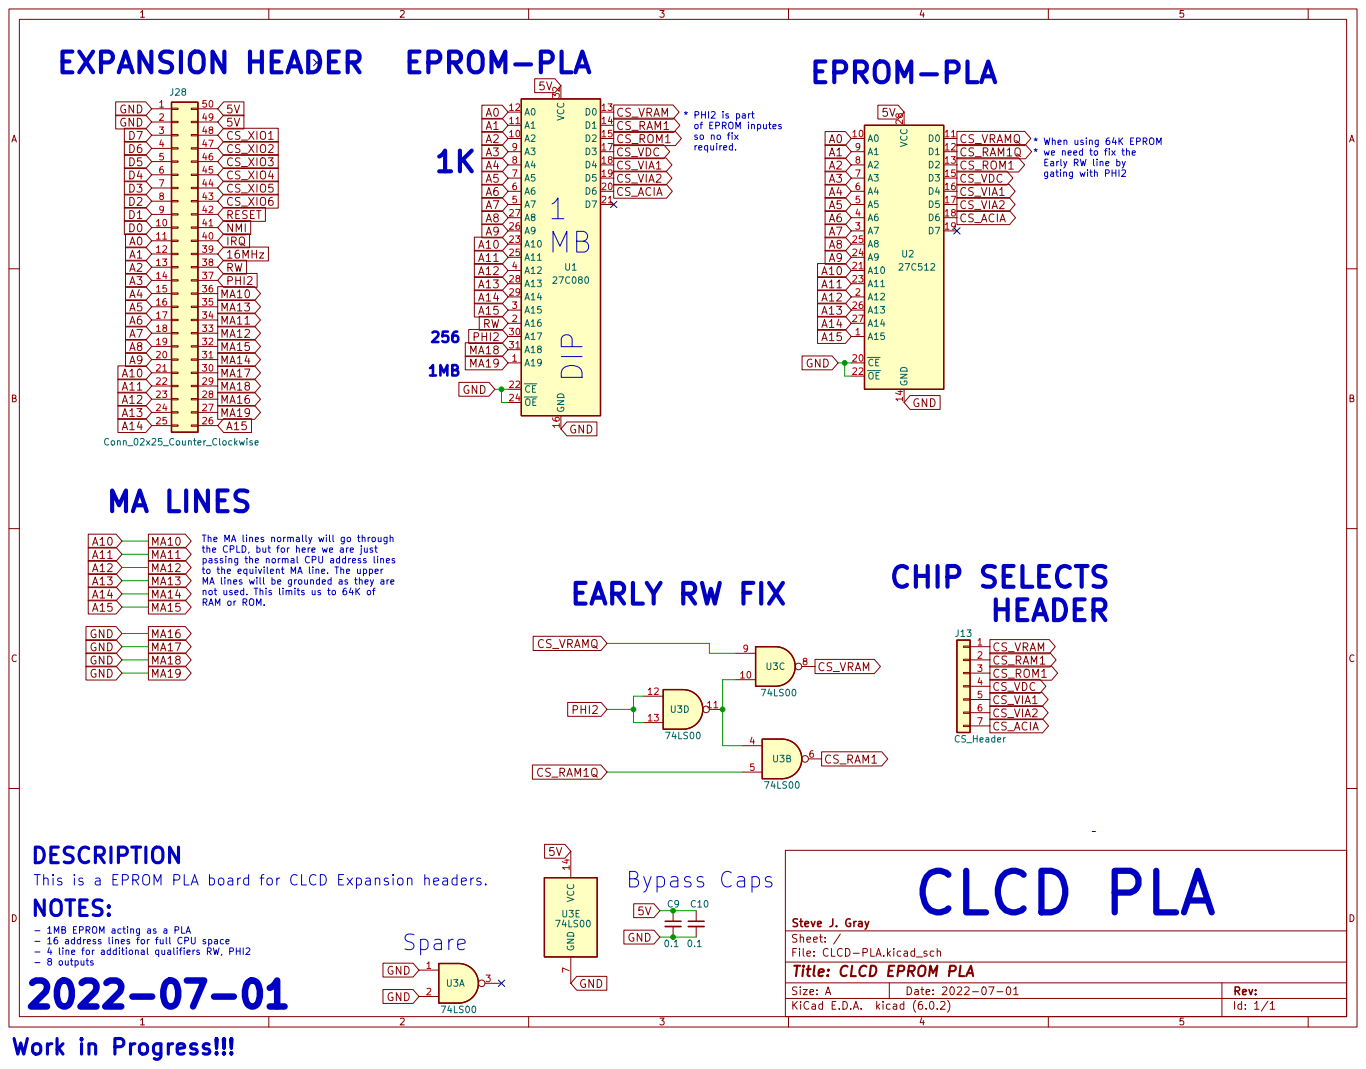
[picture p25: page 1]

* we need to fix the
Early RW line by
gating with PHI2

The MA lines normally will go through
the CPLD, but for here we are just
passing the normal CPU address lines
to the equivilent MA line. The upper
MA lines will be grounded as they are

not used. This limits us to 64K of RAM or ROM. NOTES:

DESCRIPTION
This is a EPROM PLA board for CLCD Expansion headers.

- 1MB EPROM acting as a PLA
- 16 address lines for full CPU space
- 4 line for additional qualifiers RW, PHI2
- 8 outputs

File: CLCD-PLA.kicad_sch Sheet: / Steve J. Gray

Id: 1/1 Title: CLCD EPROM PLA

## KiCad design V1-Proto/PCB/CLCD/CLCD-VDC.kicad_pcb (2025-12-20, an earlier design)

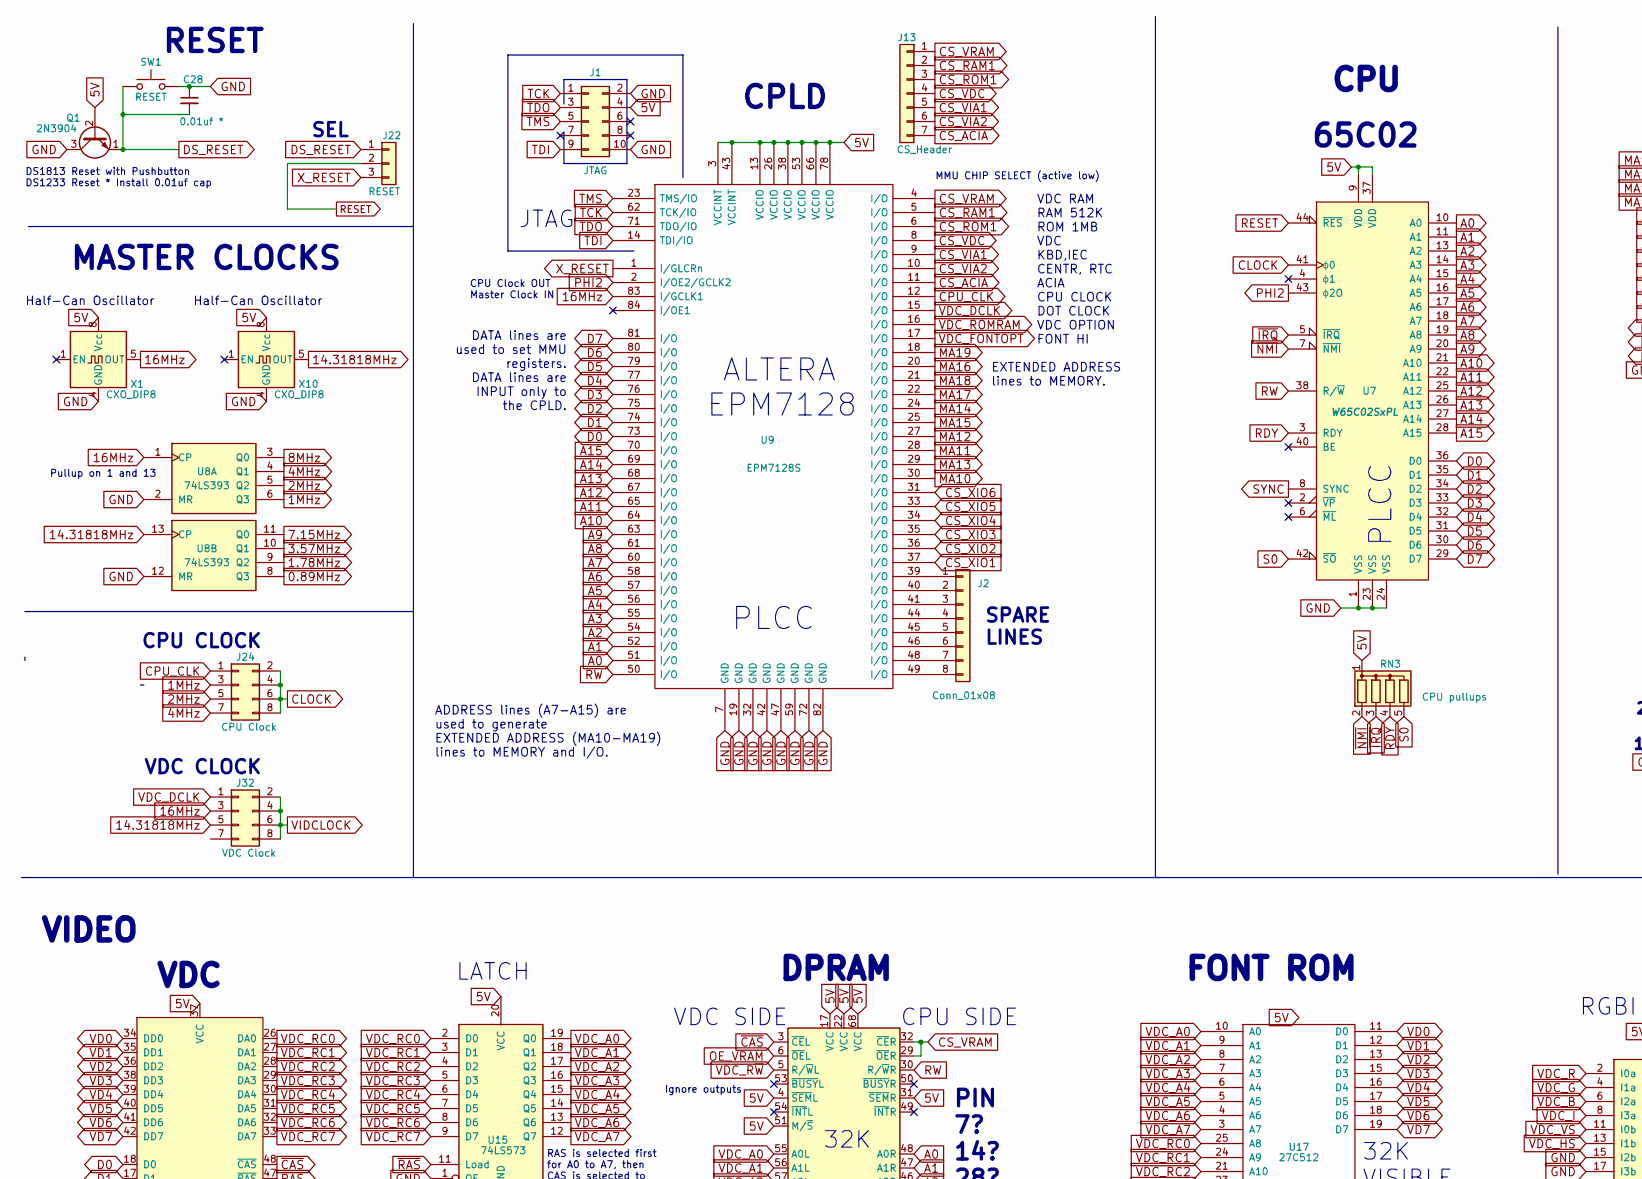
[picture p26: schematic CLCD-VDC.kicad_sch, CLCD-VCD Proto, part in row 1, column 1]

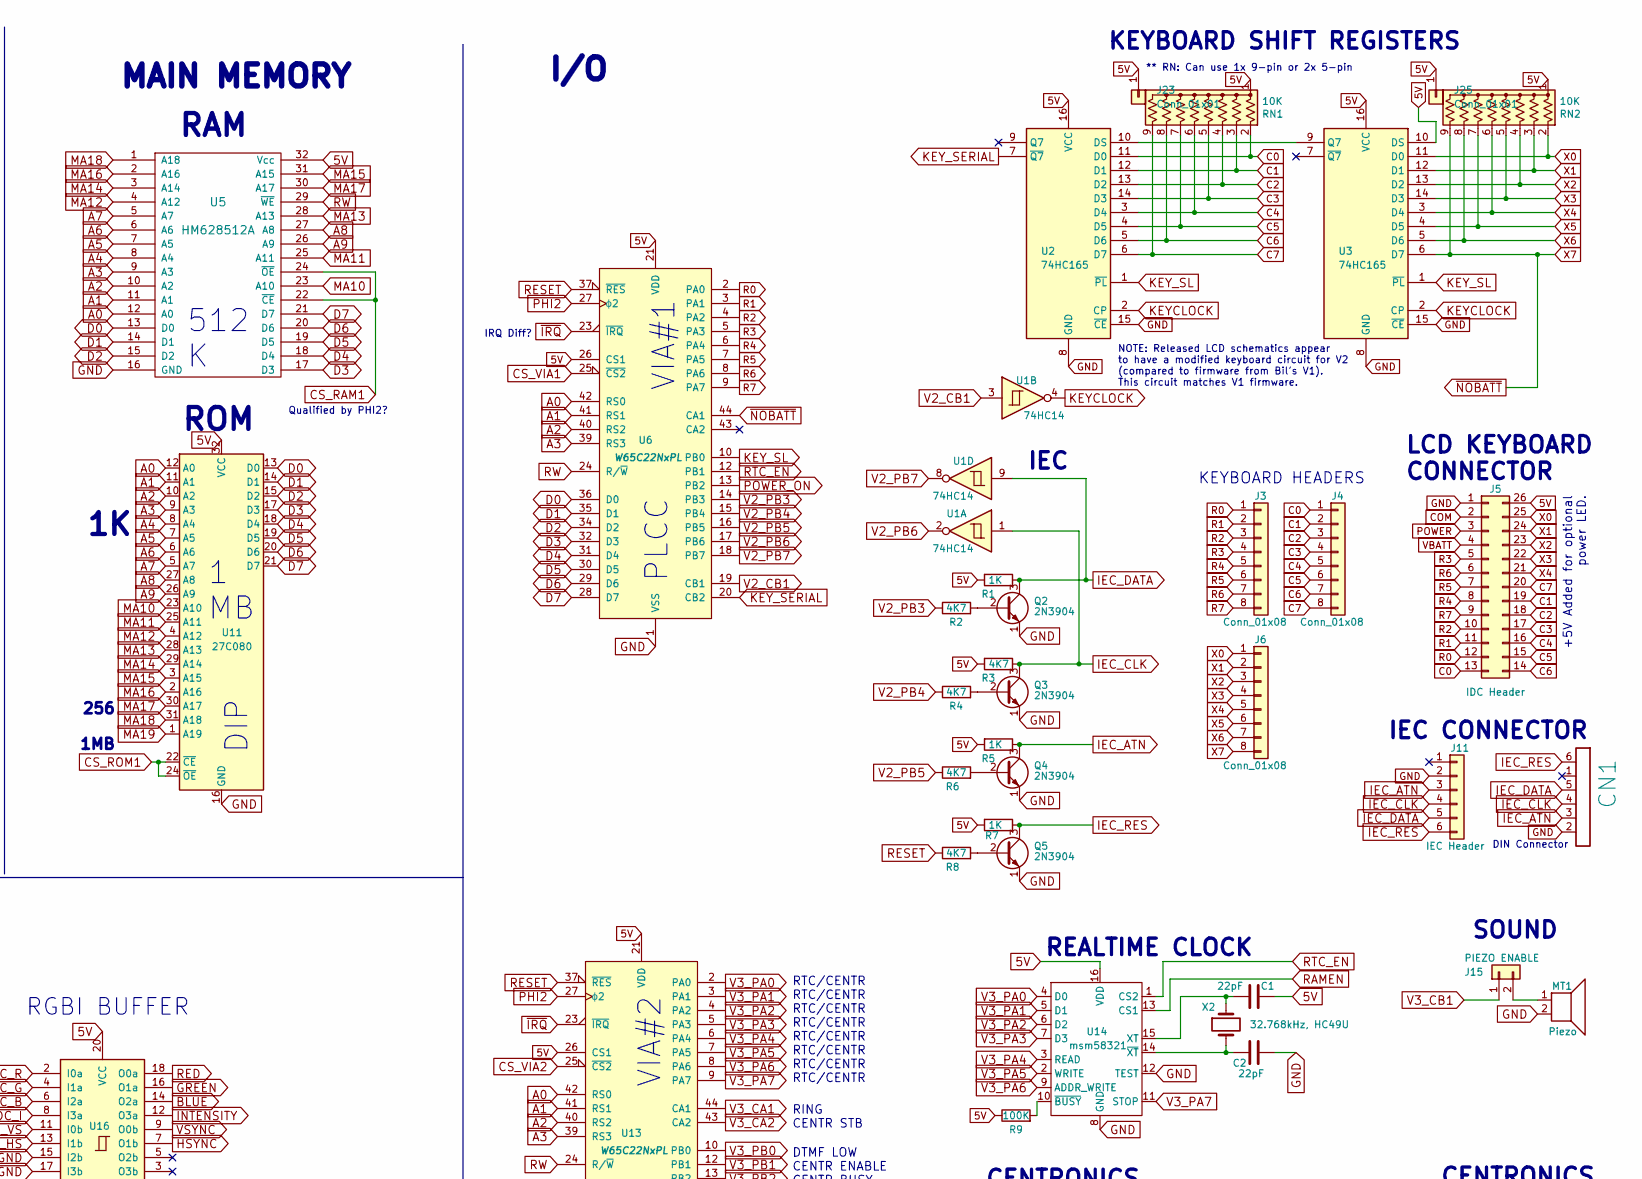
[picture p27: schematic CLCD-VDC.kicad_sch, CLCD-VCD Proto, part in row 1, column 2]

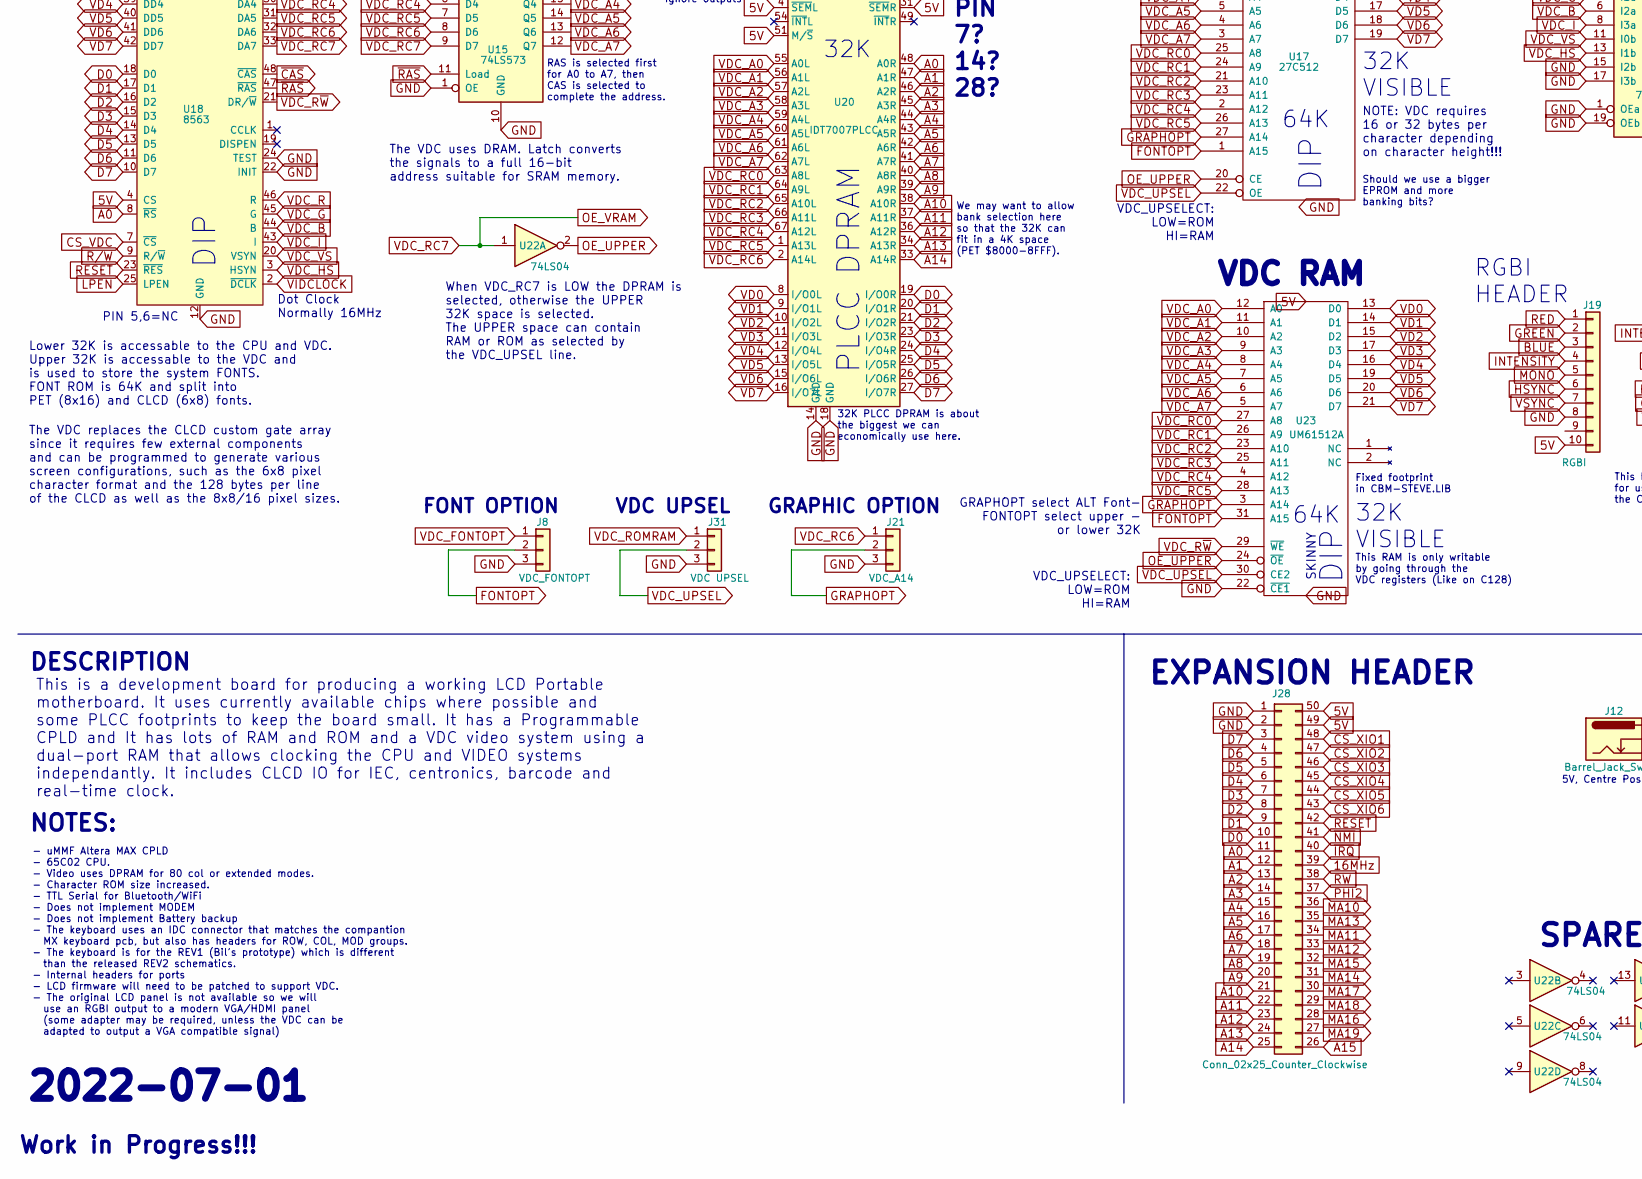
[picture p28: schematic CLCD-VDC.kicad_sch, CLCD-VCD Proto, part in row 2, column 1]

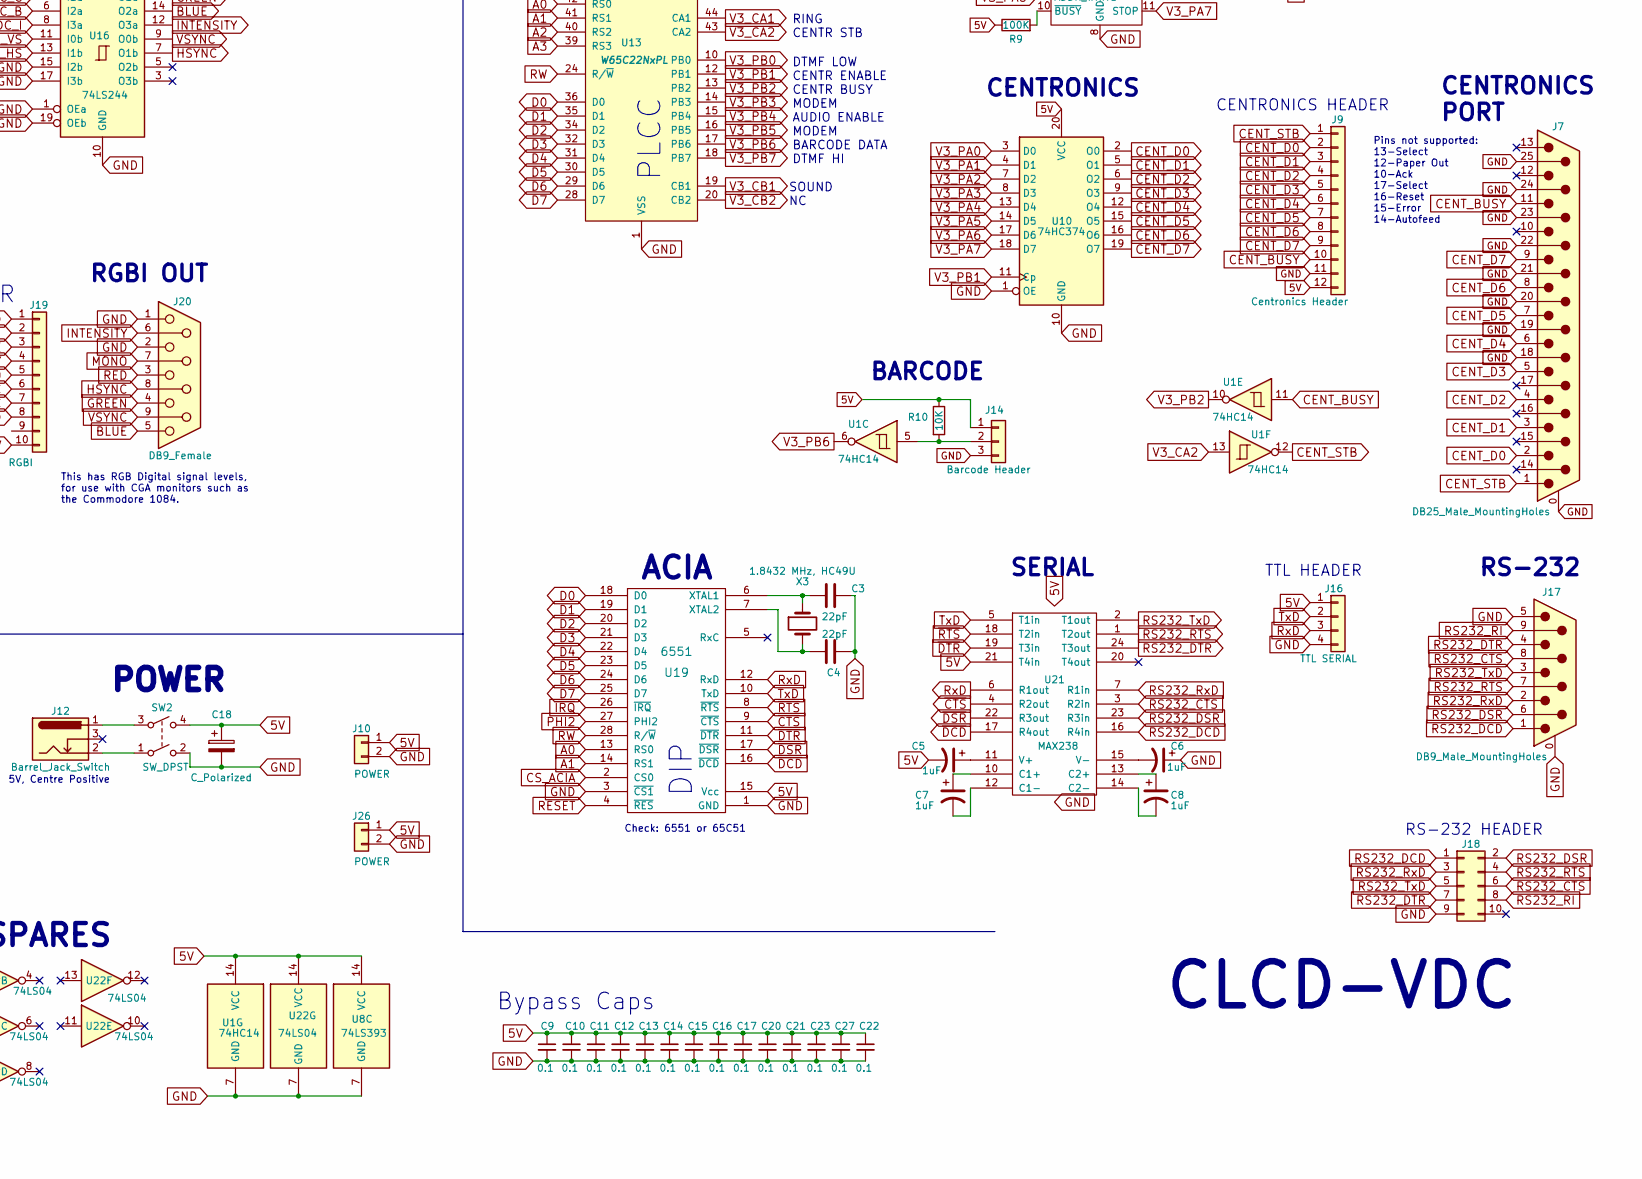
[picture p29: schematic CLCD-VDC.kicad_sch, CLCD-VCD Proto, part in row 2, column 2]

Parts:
C1, C2, C3, C4: 22pF; C_Disc_D4.7mm_W2.5mm_P5.00mm
C5, C6, C7, C8: 1uF; C_Disc_D4.7mm_W2.5mm_P5.00mm
C9, C10, C11, C12, C13, C14, C15, C16, C17, C20, C21, C22, C23, C27: 0.1; C_Disc_D4.7mm_W2.5mm_P5.00mm
C18: C_Polarized; CP_Radial_D7.5mm_P2.50mm
C28: 0.01uf *; C_Disc_D4.7mm_W2.5mm_P5.00mm
CN1: SERIAL_BUS_CON; SERIAL_CON_DIN6
J1: JTAG; PinHeader_2x05_P2.54mm_Vertical
J2, J3, J4, J6: Conn_01x08; PinHeader_1x08_P2.54mm_Vertical
J5: IDC Header; PinHeader_2x13_P2.54mm_Vertical
J7: DB25_Male_MountingHoles; DSUB-25_Male_Horizontal_P2.77x2.84mm_EdgePinOffset4.94mm_Ho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
J8: VDC_FONTOPT; PinHeader_1x03_P2.54mm_Vertical
J9: Centronics Header; PinHeader_1x12_P2.54mm_Vertical
J10, J26: POWER; PinHeader_1x02_P2.54mm_Vertical
J11: IEC Header; PinHeader_1x06_P2.54mm_Vertical
J12: Barrel_Jack_Switch; BarrelJack_Horizontal
J13: CS_Header; PinHeader_1x07_P2.54mm_Vertical
J14: Barcode Header; PinHeader_1x03_P2.54mm_Vertical
J15: PIEZO ENABLE; PinHeader_1x02_P2.54mm_Vertical
J16: TTL SERIAL; PinHeader_1x04_P2.54mm_Vertical
J17: DB9_Male_MountingHoles; DSUB-9_Male_Horizontal_P2.77x2.84mm_EdgePinOffset4.94mm_Hou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
J18: RS232 Header; PinHeader_2x05_P2.54mm_Vertical
J19: RGBI; PinHeader_1x10_P2.54mm_Vertical
J20: DB9_Female; DSUB-9_Female_Horizontal_P2.77x2.84mm_EdgePinOffset4.94mm_H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
J21: VDC_A14; PinHeader_1x03_P2.54mm_Vertical
J22: RESET; PinHeader_1x03_P2.54mm_Vertical
J23, J25: Conn_01x01; PinHeader_1x01_P2.54mm_Vertical
J24: CPU Clock; PinHeader_2x04_P2.54mm_Vertical
J28: Conn_02x25_Counter_Clockwise; PinHeader_2x25_P2.54mm_Vertical
J31: VDC UPSEL; PinHeader_1x03_P2.54mm_Vertical
J32: VDC Clock; PinHeader_2x04_P2.54mm_Vertical
MT1: Piezo; TestPoint_2Pads_Pitch2.54mm_Drill0.8mm
Q1, Q2, Q3, Q4, Q5: 2N3904; TO-92_Inline
R1, R5, R7: 1K; R_Axial_DIN0204_L3.6mm_D1.6mm_P7.62mm_Horizontal
R2, R3, R4, R6, R8: 4K7; R_Axial_DIN0204_L3.6mm_D1.6mm_P7.62mm_Horizontal
R9: 100K; R_Axial_DIN0204_L3.6mm_D1.6mm_P7.62mm_Horizontal
R10: 10K; R_Axial_DIN0204_L3.6mm_D1.6mm_P7.62mm_Horizontal
RN1, RN2: 10K; R_Array_SIP9
RN3: CPU pullups; R_Array_SIP5
SW1: RESET; SW_Tactile_SPST_Angled_PTS645Vx58-2LFS
SW2: SW_DPST; SW_Push_2P1T_Toggle_CK_PVA1xxH2xxxxxxV2
U1: 74HC14; DIP-14_W7.62mm_LongPads
U2, U3: 74HC165; DIP-16_W7.62mm_LongPads
U5: HM628512A; DIP-32_W15.24mm_LongPads
U6, U13: W65C22NxPL; PLCC-44_THT-Socket
U7: W65C02SxPL; PLCC-44_THT-Socket
U8: 74LS393; DIP-14_W7.62mm_LongPads
U9: EPM7128S; PLCC-84_THT-Socket
U10: 74HC374; DIP-20_W7.62mm_LongPads
U11: 27C080; DIP-32_W15.24mm_LongPads
U14: msm58321; DIP-16_W7.62mm_LongPads
U15: 74LS573; DIP-20_W7.62mm_LongPads
U16: 74LS244; DIP-20_W7.62mm_LongPads
U17: 27C512; DIP-28_W15.24mm_LongPads
U18: 8563; DIP-48_W15.24mm_LongPads
U19: 6551; DIP-28_W15.24mm_LongPads
U20: IDT7007PLCC; PLCC-68_THT-Socket
U21: MAX238; DIP-24_W7.62mm_LongPads
U22: 74LS04; DIP-14_W7.62mm_LongPads
U23: UM61512A; DIP-32_W7.62mm
X1, X10: CXO_DIP8; Oscillator_DIP-8
X2: 32.768kHz, HC49U; Crystal_HC49-U_Vertical
X3: 1.8432 MHz, HC49U; Crystal_HC49-U_Vertical

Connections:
0.89MHz: U8.8 (Q3)
1.78MHz: U8.9 (Q2)
1MHz: J24.3, U8.6 (Q3)
2MHz: J24.5, U8.5 (Q2)
3.57MHz: U8.10 (Q1)
4MHz: J24.7, U8.4 (Q1)
5V: C1.2, C5.2, C9.1, C10.1, C11.1, C12.1, C13.1, C14.1, C15.1, C16.1, C17.1, C18.1, C20.1, C21.1, C22.1, C23.1, C27.1, J1.4, J5.26, J9.12, J10.1, J14.1, J16.1, J19.10, J23.1, J25.1, J26.1, J28.49, J28.50, Q1.2 (B), R1.2, R3.2, R5.2, R7.2, R9.1, R10.1, RN1.1 (common), RN2.1 (common), RN3.1 (common), SW2.4, U1.14 (VCC), U2.16 (VCC), U3.10 (DS), U3.16 (VCC), U5.32 (Vcc), U6.21 (VDD), U6.26 (CS1), U7.9 (VDD), U7.37 (VDD), U8.14 (VCC), U9.3 (VCCINT), U9.13 (VCCIO), U9.26 (VCCIO), U9.38 (VCCIO), U9.43 (VCCINT), U9.53 (VCCIO), U9.66 (VCCIO), U9.78 (VCCIO), U10.20 (VCC), U11.32 (VCC), U13.21 (VDD), U13.26 (CS1), U14.16 (VDD), U15.20 (VCC), U16.20 (VCC), U17.28 (VCC), U18.4 (CS), U18.37 (VCC), U19.15 (Vcc), U20.4 (~SEML), U20.17 (VCC), U20.22 (VCC), U20.31 (~SEMR), U20.51 (M/~S), U20.68 (VCC), U21.9 (VCC), U21.21 (T4in), U22.14 (VCC), U23.32 (VCC), X1.8 (Vcc), X10.8 (Vcc)
7.15MHz: U8.11 (Q0)
8MHz: U8.3 (Q0)
14.31818MHz: J32.5, U8.13 (CP), X10.5 (OUT)
16MHz: J28.39, J32.3, U8.1 (CP), U9.83 (I/GCLK1), X1.5 (OUT)
A0: J28.11, U5.12 (A0), U6.42 (RS0), U7.10 (A0), U9.51 (I/O), U11.12 (A0), U13.42 (RS0), U18.8 (~RS), U19.13 (RS0), U20.48 (A0R)
A1: J28.12, U5.11 (A1), U6.41 (RS1), U7.11 (A1), U9.52 (I/O), U11.11 (A1), U13.41 (RS1), U19.14 (RS1), U20.47 (A1R)
A2: J28.13, U5.10 (A2), U6.40 (RS2), U7.13 (A2), U9.54 (I/O), U11.10 (A2), U13.40 (RS2), U20.46 (A2R)
A3: J28.14, U5.9 (A3), U6.39 (RS3), U7.14 (A3), U9.55 (I/O), U11.9 (A3), U13.39 (RS3), U20.45 (A3R)
A4: J28.15, U5.8 (A4), U7.15 (A4), U9.56 (I/O), U11.8 (A4), U20.44 (A4R)
A5: J28.16, U5.7 (A5), U7.16 (A5), U9.57 (I/O), U11.7 (A5), U20.43 (A5R)
A6: J28.17, U5.6 (A6), U7.17 (A6), U9.58 (I/O), U11.6 (A6), U20.42 (A6R)
A7: J28.18, U5.5 (A7), U7.18 (A7), U9.60 (I/O), U11.5 (A7), U20.41 (A7R)
A8: J28.19, U5.27 (A8), U7.19 (A8), U9.61 (I/O), U11.27 (A8), U20.40 (A8R)
A9: J28.20, U5.26 (A9), U7.20 (A9), U9.63 (I/O), U11.26 (A9), U20.39 (A9R)
A10: J28.21, U7.21 (A10), U9.64 (I/O), U20.38 (A10R)
A11: J28.22, U7.22 (A11), U9.65 (I/O), U20.37 (A11R)
A12: J28.23, U7.25 (A12), U9.67 (I/O), U20.36 (A12R)
A13: J28.24, U7.26 (A13), U9.68 (I/O), U20.34 (A13R)
A14: J28.25, U7.27 (A14), U9.69 (I/O), U20.33 (A14R)
A15: J28.26, U7.28 (A15), U9.70 (I/O)
BLUE: J19.3, J20.5, U16.14 (O2a)
C0: J4.1, J5.13, RN1.2 (R1), U2.11 (D0)
C1: J4.2, J5.19, RN1.3 (R2), U2.12 (D1)
C2: J4.3, J5.18, RN1.4 (R3), U2.13 (D2)
C3: J4.4, J5.17, RN1.5 (R4), U2.14 (D3)
C4: J4.5, J5.16, RN1.6 (R5), U2.3 (D4)
C5: J4.6, J5.15, RN1.7 (R6), U2.4 (D5)
C6: J4.7, J5.14, RN1.8 (R7), U2.5 (D6)
C7: J4.8, J5.20, RN1.9 (R8), U2.6 (D7)
CENT_BUSY: J7.11, J9.10, U1.11
CENT_D0: J7.2, J9.2, U10.2 (O0)
CENT_D1: J7.3, J9.3, U10.5 (O1)
CENT_D2: J7.4, J9.4, U10.6 (O2)
CENT_D3: J7.5, J9.5, U10.9 (O3)
CENT_D4: J7.6, J9.6, U10.12 (O4)
CENT_D5: J7.7, J9.7, U10.15 (O5)
CENT_D6: J7.8, J9.8, U10.16 (O6)
CENT_D7: J7.9, J9.9, U10.19 (O7)
CENT_STB: J7.1, J9.1, U1.12
CLOCK: J24.2, J24.4, J24.6, J24.8, U7.41 (ϕ0)
COM: J5.2
CPU_CLK: J24.1, U9.12 (I/O)
CS_ACIA: J13.7, U9.11 (I/O), U19.2 (CS0)
CS_RAM1: J13.2, U5.22 (~CE), U5.24 (~OE), U9.5 (I/O)
CS_ROM1: J13.3, U9.6 (I/O), U11.22 (~CE), U11.24 (~OE)
CS_VDC: J13.4, U9.8 (I/O), U18.7 (~CS)
CS_VIA1: J13.5, U6.25 (~CS2), U9.9 (I/O)
CS_VIA2: J13.6, U9.10 (I/O), U13.25 (~CS2)
CS_VRAM: J13.1, U9.4 (I/O), U20.29 (~OER), U20.32 (~CER)
CS_XIO1: J28.48, U9.37 (I/O)
CS_XIO2: J28.47, U9.36 (I/O)
CS_XIO3: J28.46, U9.35 (I/O)
CS_XIO4: J28.45, U9.34 (I/O)
CS_XIO5: J28.44, U9.33 (I/O)
CS_XIO6: J28.43, U9.31 (I/O)
D0: J28.10, U5.13 (D0), U6.36 (D0), U7.36 (D0), U9.73 (I/O), U11.13 (D0), U13.36 (D0), U18.18 (D0), U19.18 (D0), U20.19 (I/O0R)
D1: J28.9, U5.14 (D1), U6.35 (D1), U7.35 (D1), U9.74 (I/O), U11.14 (D1), U13.35 (D1), U18.17 (D1), U19.19 (D1), U20.20 (I/O1R)
D2: J28.8, U5.15 (D2), U6.34 (D2), U7.34 (D2), U9.75 (I/O), U11.15 (D2), U13.34 (D2), U18.16 (D2), U19.20 (D2), U20.21 (I/O2R)
D3: J28.7, U5.17 (D3), U6.32 (D3), U7.33 (D3), U9.76 (I/O), U11.17 (D3), U13.32 (D3), U18.15 (D3), U19.21 (D3), U20.23 (I/O3R)
D4: J28.6, U5.18 (D4), U6.31 (D4), U7.32 (D4), U9.77 (I/O), U11.18 (D4), U13.31 (D4), U18.14 (D4), U19.22 (D4), U20.24 (I/O4R)
D5: J28.5, U5.19 (D5), U6.30 (D5), U7.31 (D5), U9.79 (I/O), U11.19 (D5), U13.30 (D5), U18.13 (D5), U19.23 (D5), U20.25 (I/O5R)
D6: J28.4, U5.20 (D6), U6.29 (D6), U7.30 (D6), U9.80 (I/O), U11.20 (D6), U13.29 (D6), U18.11 (D6), U19.24 (D6), U20.26 (I/O6R)
D7: J28.3, U5.21 (D7), U6.28 (D7), U7.29 (D7), U9.81 (I/O), U11.21 (D7), U13.28 (D7), U18.10 (D7), U19.25 (D7), U20.27 (I/O7R)
DS_RESET: C28.2, J22.1, Q1.1 (E), SW1.1
FONTOPT: J8.2, U17.1 (A15), U23.31 (A15)
GND: C2.2, C3.2, C4.2, C6.1, C9.2, C10.2, C11.2, C12.2, C13.2, C14.2, C15.2, C16.2, C17.2, C18.2, C20.2, C21.2, C22.2, C23.2, C27.2, C28.1, CN1.2, J1.2, J1.10, J5.1, J7.0 (PAD), J7.18, J7.19, J7.20, J7.21, J7.22, J7.23, J7.24, J7.25, J8.3, J9.11, J10.2, J11.2, J14.3, J16.4, J17.0 (PAD), J17.5, J18.9, J19.8, J20.1, J20.2, J21.3, J26.2, J28.1, J28.2, J31.3, MT1.2, Q1.3 (C), Q2.1 (E), Q3.1 (E), Q4.1 (E), Q5.1 (E), SW1.2, SW2.2, U1.7 (GND), U2.8 (GND), U2.15 (~CE), U3.8 (GND), U3.15 (~CE), U5.16 (GND), U6.1 (VSS), U7.1 (VSS), U7.23 (VSS), U7.24 (VSS), U8.2 (MR), U8.7 (GND), U8.12 (MR), U9.7 (GND), U9.19 (GND), U9.32 (GND), U9.42 (GND), U9.47 (GND), U9.59 (GND), U9.72 (GND), U9.82 (GND), U10.1 (OE), U10.10 (GND), U11.16 (GND), U13.1 (VSS), U14.8 (GND), U14.12 (TEST), U15.1 (OE), U15.10 (GND), U16.1 (OEa), U16.10 (GND), U16.15 (I2b), U16.17 (I3b), U16.19 (OEb), U17.14 (GND), U18.12 (GND), U18.22 (INIT), U18.24 (TEST), U19.1 (GND), U19.3 (~CS1), U20.14 (GND), U20.18 (GND), U21.8 (GND), U22.7 (GND), U23.18 (GND), U23.22 (~CE1), X1.4 (GND), X10.4 (GND)
GRAPHOPT: J21.2, U17.27 (A14), U23.3 (A14)
GREEN: J19.2, J20.4, U16.16 (O1a)
HSYNC: J19.6, J20.8, U16.7 (O1b)
IEC_ATN: CN1.3, J11.3, Q4.3 (C), R5.1
IEC_CLK: CN1.4, J11.4, Q3.3 (C), R3.1, U1.1
IEC_DATA: CN1.5, J11.5, Q2.3 (C), R1.1, U1.9
IEC_RES: CN1.6, J11.6, Q5.3 (C), R7.1
INTENSITY: J19.4, J20.6, U16.12 (O3a)
KEYCLOCK: U1.4, U2.2 (CP), U3.2 (CP)
KEY_SERIAL: U2.7 (~Q7), U6.20 (CB2)
KEY_SL: U2.1 (~PL), U3.1 (~PL), U6.10 (PB0)
LPEN: U18.25 (LPEN)
MA10: J28.36, U5.23 (A10), U9.30 (I/O), U11.23 (A10)
MA11: J28.34, U5.25 (A11), U9.28 (I/O), U11.25 (A11)
MA12: J28.33, U5.4 (A12), U9.27 (I/O), U11.4 (A12)
MA13: J28.35, U5.28 (A13), U9.29 (I/O), U11.28 (A13)
MA14: J28.31, U5.3 (A14), U9.24 (I/O), U11.29 (A14)
MA15: J28.32, U5.31 (A15), U9.25 (I/O), U11.3 (A15)
MA16: J28.28, U5.2 (A16), U9.20 (I/O), U11.2 (A16)
MA17: J28.30, U5.30 (A17), U9.22 (I/O), U11.30 (A17)
MA18: J28.29, U5.1 (A18), U9.21 (I/O), U11.31 (A18)
MA19: J28.27, U9.18 (I/O), U11.1 (A19)
MONO: J19.5, J20.7
unnamed: C1.1, U14.15 (XT), X2.1
unnamed: C2.1, U14.14 (~XT), X2.2
unnamed: C3.1, U19.6 (XTAL1), X3.1
unnamed: C4.1, U19.7 (XTAL2), X3.2
unnamed: C5.1, U21.11 (V+)
unnamed: C6.2, U21.15 (V-)
unnamed: C7.1, U21.10 (C1+)
unnamed: C7.2, U21.12 (C1-)
unnamed: C8.1, U21.13 (C2+)
unnamed: C8.2, U21.14 (C2-)
unnamed: J12.1, SW2.3
unnamed: J12.2, SW2.1
unnamed: J14.2, R10.2, U1.5
unnamed: J15.2, MT1.1
unnamed: Q2.2 (B), R2.2
unnamed: Q3.2 (B), R4.2
unnamed: Q4.2 (B), R6.2
unnamed: Q5.2 (B), R8.2
unnamed: R9.2, U14.10 (~BUSY)
unnamed: U2.10 (DS), U3.9 (Q7)
unnamed: J2.1, U9.39 (I/O)
unnamed: J2.2, U9.40 (I/O)
unnamed: J2.3, U9.41 (I/O)
unnamed: J2.4, U9.44 (I/O)
unnamed: J2.5, U9.45 (I/O)
unnamed: J2.6, U9.46 (I/O)
unnamed: J2.7, U9.48 (I/O)
unnamed: J2.8, U9.49 (I/O)
OE_UPPER: U17.20 (CE), U22.2, U23.24 (~OE)
PHI2: J28.37, U6.27 (ϕ2), U7.43 (ϕ2O), U9.2 (I/OE2/GCLK2), U13.27 (ϕ2), U19.27 (PHI2)
POWER: J5.3
POWER_ON: U6.13 (PB2)
R0: J3.1, J5.12, U6.2 (PA0)
R1: J3.2, J5.11, U6.3 (PA1)
R2: J3.3, J5.10, U6.4 (PA2)
R3: J3.4, J5.5, U6.5 (PA3)
R4: J3.5, J5.8, U6.6 (PA4)
R5: J3.6, J5.7, U6.7 (PA5)
R6: J3.7, J5.6, U6.8 (PA6)
R7: J3.8, J5.9, U6.9 (PA7)
RAMEN: U14.13 (CS1)
RDY: RN3.4 (R3), U7.3 (RDY)
RED: J19.1, J20.3, U16.18 (O0a)
RESET: J22.2, J28.42, R8.1, U6.37 (~RES), U7.44 (~RES), U13.37 (~RES), U18.23 (~RES), U19.4 (~RES)
RS232_CTS: J17.8, J18.6, U21.3 (R2in)
RS232_DCD: J17.1, J18.1, U21.16 (R4in)
RS232_DSR: J17.6, J18.2, U21.23 (R3in)
RS232_DTR: J17.4, J18.7, U21.24 (T3out)
RS232_RI: J17.9, J18.8
RS232_RTS: J17.7, J18.4, U21.1 (T2out)
RS232_RxD: J17.2, J18.3, U21.7 (R1in)
RS232_TxD: J17.3, J18.5, U21.2 (T1out)
RTC_EN: U6.12 (PB1), U14.1 (CS2)
RW: J28.38, U5.29 (~WE), U6.24 (R/~W), U7.38 (R/~W), U9.50 (I/O), U13.24 (R/~W), U19.28 (R/~W), U20.30 (R/~WR)
RxD: J16.3, U19.12 (RxD), U21.6 (R1out)
R/W: U18.9 (R/~W)
S0: RN3.5 (R4), U7.42 (~SO)
SYNC: U7.8 (SYNC)
TCK: J1.1, U9.62 (TCK/IO)
TDI: J1.9, U9.14 (TDI/IO)
TDO: J1.3, U9.71 (TDO/IO)
TMS: J1.5, U9.23 (TMS/IO)
TxD: J16.2, U19.10 (TxD), U21.5 (T1in)
V2_CB1: U1.3, U6.19 (CB1)
V2_PB3: R2.1, U6.14 (PB3)
V2_PB4: R4.1, U6.15 (PB4)
V2_PB5: R6.1, U6.16 (PB5)
V2_PB6: U1.2, U6.17 (PB6)
V2_PB7: U1.8, U6.18 (PB7)
V3_CA1: U13.44 (CA1)
V3_CA2: U1.13, U13.43 (CA2)
V3_CB1: J15.1, U13.19 (CB1)
V3_CB2: U13.20 (CB2)
V3_PA0: U10.3 (D0), U13.2 (PA0), U14.4 (D0)
V3_PA1: U10.4 (D1), U13.3 (PA1), U14.5 (D1)
V3_PA2: U10.7 (D2), U13.4 (PA2), U14.6 (D2)
V3_PA3: U10.8 (D3), U13.5 (PA3), U14.7 (D3)
V3_PA4: U10.13 (D4), U13.6 (PA4), U14.3 (READ)
V3_PA5: U10.14 (D5), U13.7 (PA5), U14.2 (WRITE)
V3_PA6: U10.17 (D6), U13.8 (PA6), U14.9 (ADDR_WRITE)
V3_PA7: U10.18 (D7), U13.9 (PA7), U14.11 (STOP)
V3_PB0: U13.10 (PB0)
V3_PB1: U10.11 (Cp), U13.12 (PB1)
V3_PB2: U1.10, U13.13 (PB2)
V3_PB3: U13.14 (PB3)
V3_PB4: U13.15 (PB4)
V3_PB5: U13.16 (PB5)
V3_PB6: U1.6, U13.17 (PB6)
V3_PB7: U13.18 (PB7)
VBATT: J5.4
VD0: U17.11 (D0), U18.34 (DD0), U20.8 (I/O0L), U23.13 (D0)
VD1: U17.12 (D1), U18.35 (DD1), U20.9 (I/O1L), U23.14 (D1)
VD2: U17.13 (D2), U18.36 (DD2), U20.10 (I/O2L), U23.15 (D2)
VD3: U17.15 (D3), U18.38 (DD3), U20.11 (I/O3L), U23.17 (D3)
VD4: U17.16 (D4), U18.39 (DD4), U20.12 (I/O4L), U23.16 (D4)
VD5: U17.17 (D5), U18.40 (DD5), U20.13 (I/O5L), U23.19 (D5)
VD6: U17.18 (D6), U18.41 (DD6), U20.15 (I/O6L), U23.20 (D6)
VD7: U17.19 (D7), U18.42 (DD7), U20.16 (I/O7L), U23.21 (D7)
VDC_A0: U15.19 (Q0), U17.10 (A0), U20.55 (A0L), U23.12 (A0)
VDC_A1: U15.18 (Q1), U17.9 (A1), U20.56 (A1L), U23.11 (A1)
VDC_A2: U15.17 (Q2), U17.8 (A2), U20.57 (A2L), U23.10 (A2)
VDC_A3: U15.16 (Q3), U17.7 (A3), U20.58 (A3L), U23.9 (A3)
VDC_A4: U15.15 (Q4), U17.6 (A4), U20.59 (A4L), U23.8 (A4)
VDC_A5: U15.14 (Q5), U17.5 (A5), U20.60 (A5L), U23.7 (A5)
VDC_A6: U15.13 (Q6), U17.4 (A6), U20.61 (A6L), U23.6 (A6)
VDC_A7: U15.12 (Q7), U17.3 (A7), U20.62 (A7L), U23.5 (A7)
VDC_B: U16.6 (I2a), U18.44 (B)
VDC_DCLK: J32.1, U9.15 (I/O)
VDC_FONTOPT: J8.1, U9.17 (I/O)
VDC_G: U16.4 (I1a), U18.45 (G)
VDC_HS: U16.13 (I1b), U18.3 (HSYN)
VDC_I: U16.8 (I3a), U18.43 (I)
VDC_R: U16.2 (I0a), U18.46 (R)
VDC_RC0: U15.2 (D0), U17.25 (A8), U18.26 (DA0), U20.63 (A8L), U23.27 (A8)
VDC_RC1: U15.3 (D1), U17.24 (A9), U18.27 (DA1), U20.64 (A9L), U23.26 (A9)
VDC_RC2: U15.4 (D2), U17.21 (A10), U18.28 (DA2), U20.65 (A10L), U23.23 (A10)
VDC_RC3: U15.5 (D3), U17.23 (A11), U18.29 (DA3), U20.66 (A11L), U23.25 (A11)
VDC_RC4: U15.6 (D4), U17.2 (A12), U18.30 (DA4), U20.67 (A12L), U23.4 (A12)
VDC_RC5: U15.7 (D5), U17.26 (A13), U18.31 (DA5), U20.1 (A13L), U23.28 (A13)
VDC_RC6: J21.1, U15.8 (D6), U18.32 (DA6), U20.2 (A14L)
VDC_RC7: U15.9 (D7), U18.33 (DA7), U20.6 (~OEL), U22.1
VDC_ROMRAM: J31.1, U9.16 (I/O)
VDC_R~W: U18.21 (DR/~W), U20.5 (R/~WL), U23.29 (~WE)
VDC_UPSEL: J31.2, U17.22 (OE), U23.30 (CE2)
VDC_VS: U16.11 (I0b), U18.20 (VSYN)
VIDCLOCK: J32.2, J32.4, J32.6, J32.8, U18.2 (~DCLK)
VSYNC: J19.7, J20.9, U16.9 (O0b)
X0: J5.25, J6.1, RN2.2 (R1), U3.11 (D0)
X1: J5.24, J6.2, RN2.3 (R2), U3.12 (D1)
X2: J5.23, J6.3, RN2.4 (R3), U3.13 (D2)
X3: J5.22, J6.4, RN2.5 (R4), U3.14 (D3)
X4: J5.21, J6.5, RN2.6 (R5), U3.3 (D4)
X5: J6.6, RN2.7 (R6), U3.4 (D5)
X6: J6.7, RN2.8 (R7), U3.5 (D6)
X7: J6.8, RN2.9 (R8), U3.6 (D7), U6.44 (CA1)
X_RESET: J22.3, U9.1 (I/GLCRn)
~CAS: U18.48 (~CAS), U20.3 (~CEL)
~CTS: U19.9 (~CTS), U21.4 (R2out)
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

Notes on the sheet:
VDC_UPSELECT: LOW=ROM HI=RAM
SEL
DESCRIPTION
RGBI OUT
I/O
RTC/CENTR RTC/CENTR RTC/CENTR RTC/CENTR RTC/CENTR RTC/CENTR RTC/CENTR RTC/CENTR
IEC
ROM
TTL HEADER
PLCC
MAIN MEMORY
RGBI BUFFER
JTAG
CPLD
VIA#1
NOTE: VDC requires 16 or 32 bytes per character depending on character height!!!
Pins not supported: 13-Select 12-Paper Out 10-Ack 17-Select 16-Reset 15-Error 14-Autofeed
VDC RAM
PIN 7? 14? 28?
KEYBOARD HEADERS
CPU SIDE
REALTIME CLOCK
KEYBOARD SHIFT REGISTERS
Work in Progress!!!
MASTER CLOCKS
Dot Clock Normally 16MHz
Should we use a bigger EPROM and more banking bits?
VDC SIDE
Half-Can Oscillator
NOTES:
ACIA
DIP
EXTENDED ADDRESS lines to MEMORY.
FONT ROM
IEC CONNECTOR
EPM7128
This is a development board for producing a working LCD Portable motherboard. It uses currently available chips where possible and some PLCC footprints to keep the board small. It has a Programmable CPLD and It has lots of RAM and ROM and a VDC video system using a dual-port RAM that allows clockin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
DIN Connector
DS1813 Reset with Pushbutton DS1233 Reset * Install 0.01uf cap
64K

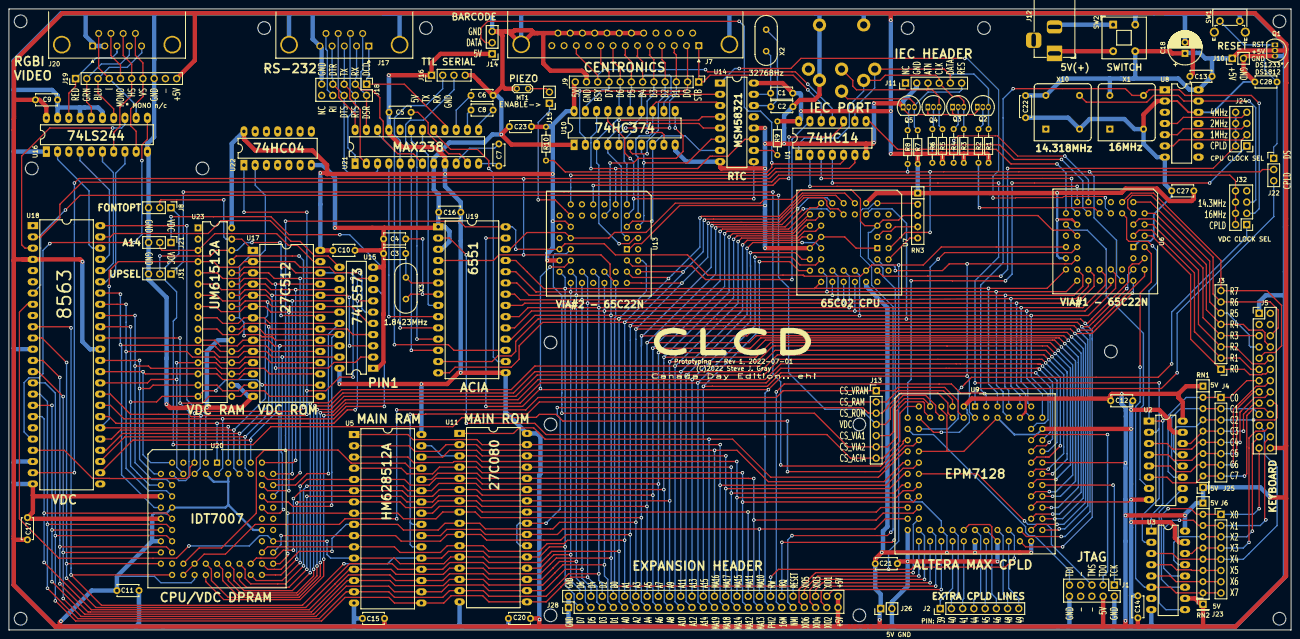
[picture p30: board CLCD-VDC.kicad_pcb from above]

Board: 2 copper layers, 290.0 x 140.5 mm, 100 parts (0 on the bottom side), 221 nets.

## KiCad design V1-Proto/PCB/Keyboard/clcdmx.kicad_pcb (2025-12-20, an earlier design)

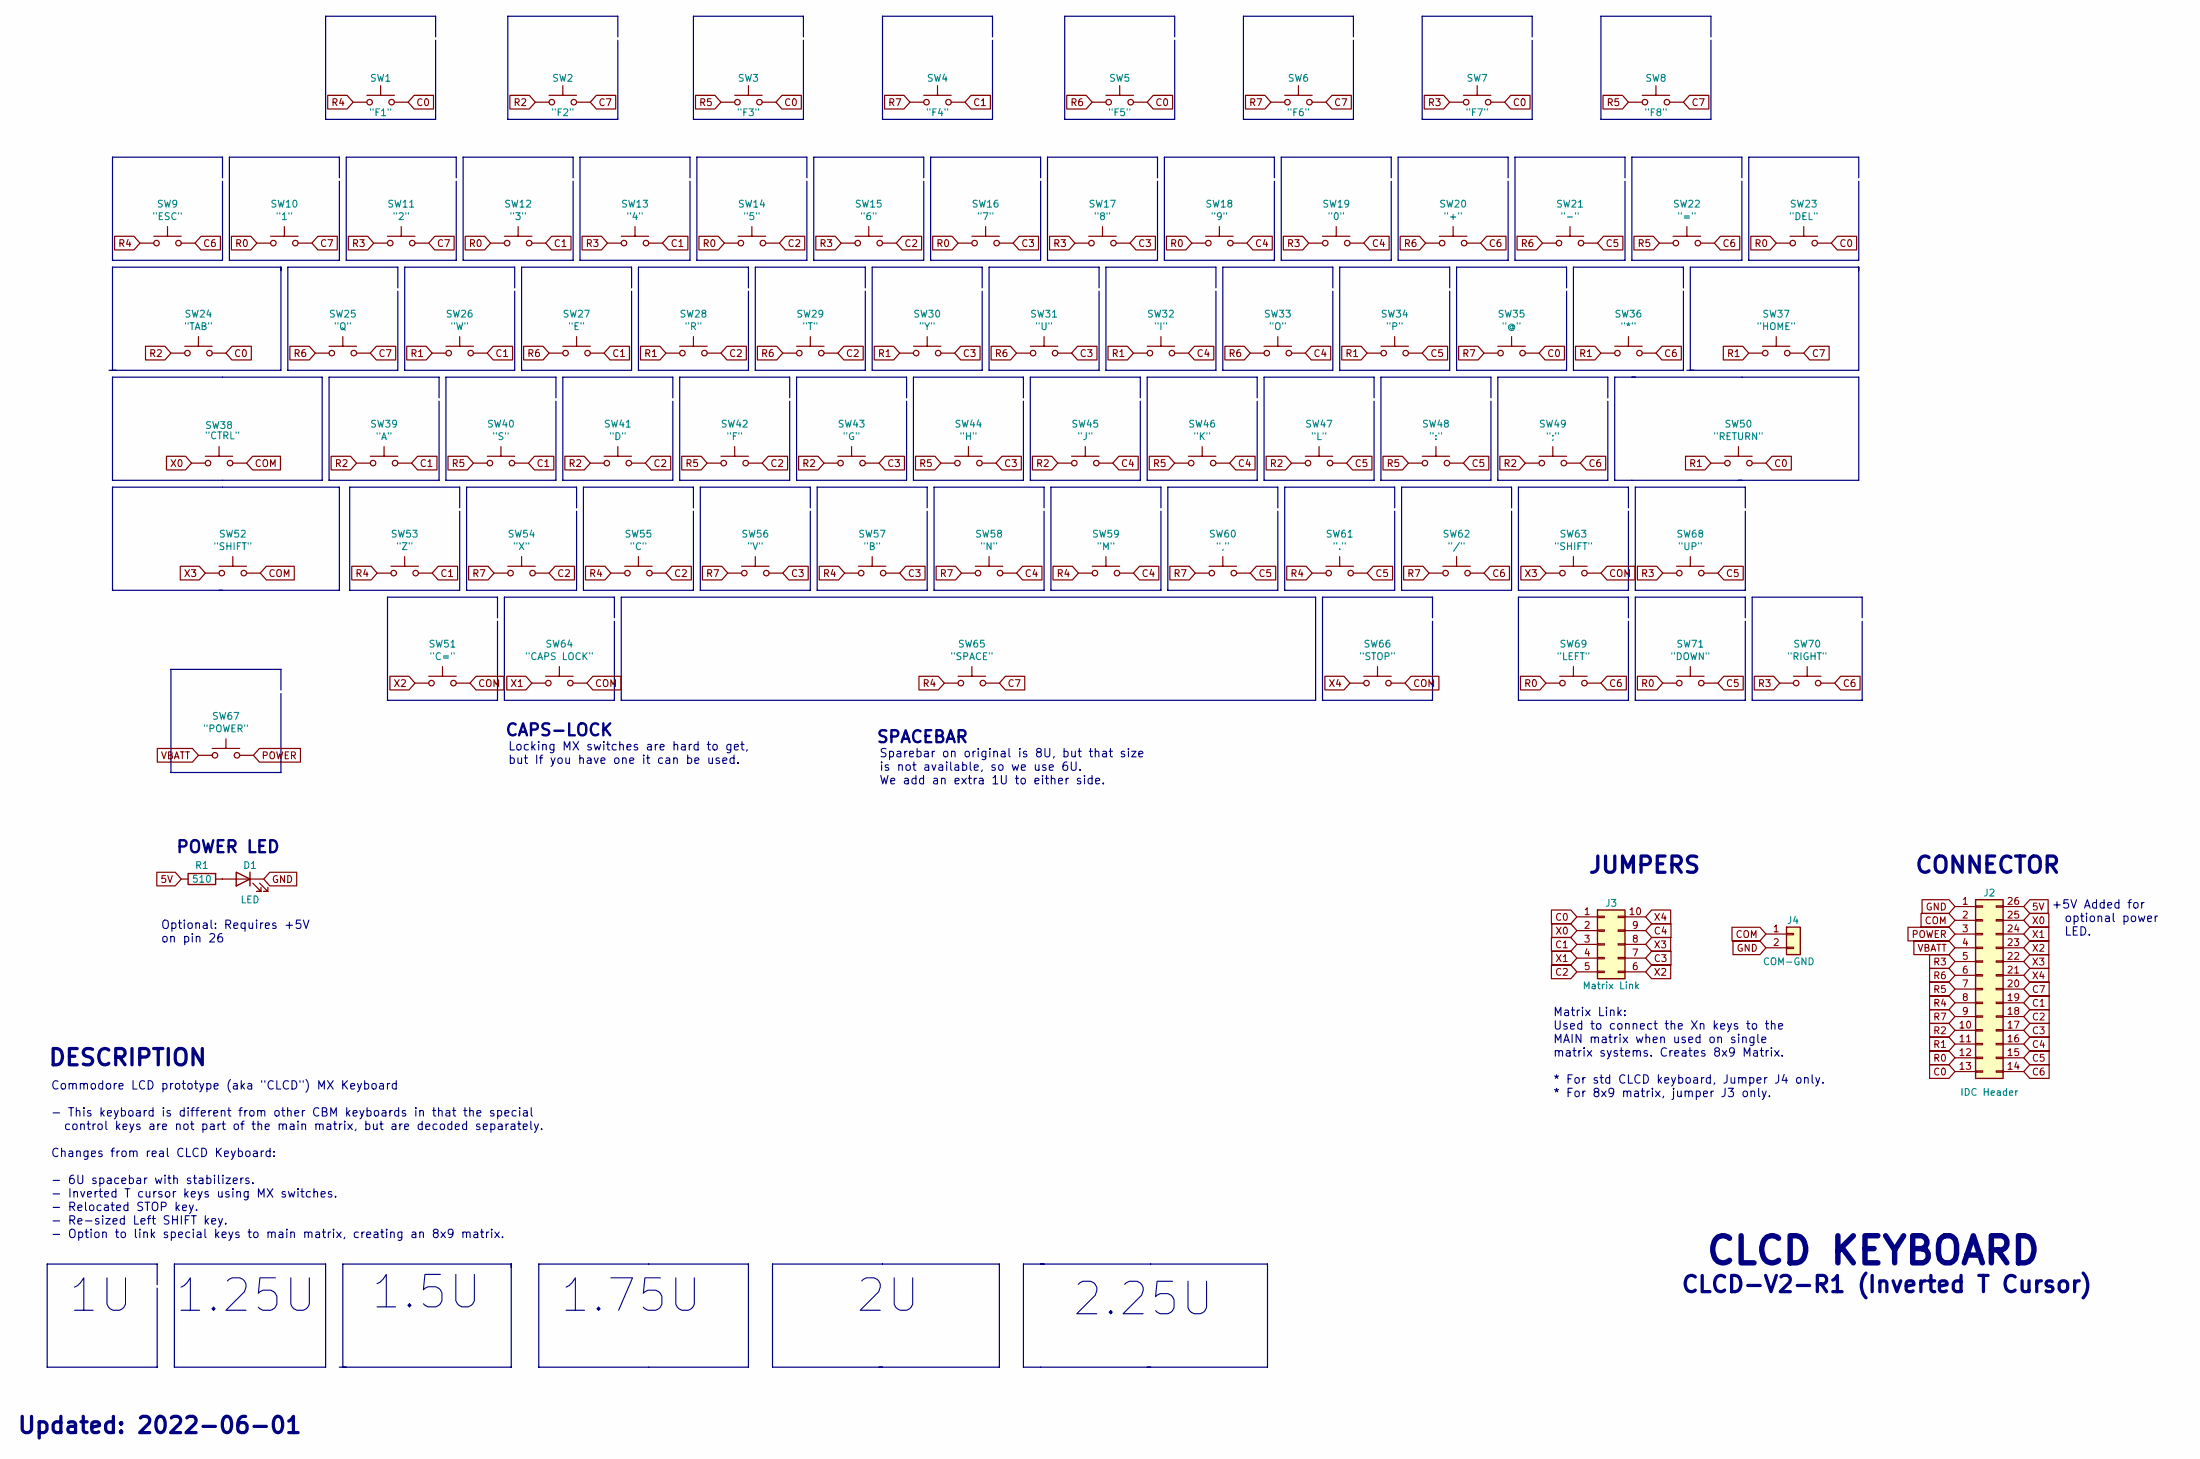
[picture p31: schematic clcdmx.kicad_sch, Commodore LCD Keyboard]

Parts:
D1: LED; PinHeader_2x01_P2.54mm_Vertical
J2: IDC Header; PinHeader_2x13_P2.54mm_Vertical
J3: Matrix Link; PinHeader_2x05_P2.54mm_Vertical
J4: COM-GND; PinHeader_1x02_P2.54mm_Vertical
R1: 510; R_Axial_DIN0204_L3.6mm_D1.6mm_P7.62mm_Horizontal
SW1: "F1"; SW_Cherry_MX_1.25u_PCB
SW2: "F2"; SW_Cherry_MX_1.25u_PCB
SW3: "F3"; SW_Cherry_MX_1.25u_PCB
SW4: "F4"; SW_Cherry_MX_1.25u_PCB
SW5: "F5"; SW_Cherry_MX_1.25u_PCB
SW6: "F6"; SW_Cherry_MX_1.25u_PCB
SW7: "F7"; SW_Cherry_MX_1.25u_PCB
SW8: "F8"; SW_Cherry_MX_1.25u_PCB
SW9: "ESC"; SW_Cherry_MX_1.00u_PCB
SW10: "1"; SW_Cherry_MX_1.00u_PCB
SW11: "2"; SW_Cherry_MX_1.00u_PCB
SW12: "3"; SW_Cherry_MX_1.00u_PCB
SW13: "4"; SW_Cherry_MX_1.00u_PCB
SW14: "5"; SW_Cherry_MX_1.00u_PCB
SW15: "6"; SW_Cherry_MX_1.00u_PCB
SW16: "7"; SW_Cherry_MX_1.00u_PCB
SW17: "8"; SW_Cherry_MX_1.00u_PCB
SW18: "9"; SW_Cherry_MX_1.00u_PCB
SW19: "0"; SW_Cherry_MX_1.00u_PCB
SW20: "+"; SW_Cherry_MX_1.00u_PCB
SW21: "-"; SW_Cherry_MX_1.00u_PCB
SW22: "="; SW_Cherry_MX_1.00u_PCB
SW23: "DEL"; SW_Cherry_MX_1.00u_PCB
SW24: "TAB"; SW_Cherry_MX_1.50u_PCB
SW25: "Q"; SW_Cherry_MX_1.00u_PCB
SW26: "W"; SW_Cherry_MX_1.00u_PCB
SW27: "E"; SW_Cherry_MX_1.00u_PCB
SW28: "R"; SW_Cherry_MX_1.00u_PCB
SW29: "T"; SW_Cherry_MX_1.00u_PCB
SW30: "Y"; SW_Cherry_MX_1.00u_PCB
SW31: "U"; SW_Cherry_MX_1.00u_PCB
SW32: "I"; SW_Cherry_MX_1.00u_PCB
SW33: "O"; SW_Cherry_MX_1.00u_PCB
SW34: "P"; SW_Cherry_MX_1.00u_PCB
SW35: "@"; SW_Cherry_MX_1.00u_PCB
SW36: "*"; SW_Cherry_MX_1.00u_PCB
SW37: "HOME"; SW_Cherry_MX_1.50u_PCB
SW38: "CTRL"; SW_Cherry_MX_1.75u_PCB
SW39: "A"; SW_Cherry_MX_1.00u_PCB
SW40: "S"; SW_Cherry_MX_1.00u_PCB
SW41: "D"; SW_Cherry_MX_1.00u_PCB
SW42: "F"; SW_Cherry_MX_1.00u_PCB
SW43: "G"; SW_Cherry_MX_1.00u_PCB
SW44: "H"; SW_Cherry_MX_1.00u_PCB
SW45: "J"; SW_Cherry_MX_1.00u_PCB
SW46: "K"; SW_Cherry_MX_1.00u_PCB
SW47: "L"; SW_Cherry_MX_1.00u_PCB
SW48: ":"; SW_Cherry_MX_1.00u_PCB
SW49: ";"; SW_Cherry_MX_1.00u_PCB
SW50: "RETURN"; SW_Cherry_MX_2.25u_PCB
SW51: "C="; SW_Cherry_MX_1.00u_PCB
SW52: "SHIFT"; SW_Cherry_MX_2.00u_PCB
SW53: "Z"; SW_Cherry_MX_1.00u_PCB
SW54: "X"; SW_Cherry_MX_1.00u_PCB
SW55: "C"; SW_Cherry_MX_1.00u_PCB
SW56: "V"; SW_Cherry_MX_1.00u_PCB
SW57: "B"; SW_Cherry_MX_1.00u_PCB
SW58: "N"; SW_Cherry_MX_1.00u_PCB
SW59: "M"; SW_Cherry_MX_1.00u_PCB
SW60: ","; SW_Cherry_MX_1.00u_PCB
SW61: "."; SW_Cherry_MX_1.00u_PCB
SW62: "/"; SW_Cherry_MX_1.00u_PCB
SW63: "SHIFT"; SW_Cherry_MX_1.00u_PCB
SW64: "CAPS LOCK"; SW_Cherry_MX_1.00u_PCB
SW65: "SPACE"; SW_Cherry_MX_6.0u_PCB
SW66: "STOP"; SW_Cherry_MX_1.00u_PCB
SW67: "POWER"; SW_Cherry_MX_1.00u_PCB
SW68: "UP"; SW_Cherry_MX_1.00u_PCB
SW69: "LEFT"; SW_Cherry_MX_1.00u_PCB
SW70: "RIGHT"; SW_Cherry_MX_1.00u_PCB
SW71: "DOWN"; SW_Cherry_MX_1.00u_PCB

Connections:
5V: J2.26, R1.1
C0: J2.13, J3.1, SW1.2, SW3.2, SW5.2, SW7.2, SW23.2, SW24.2, SW35.2, SW50.2
C1: J2.19, J3.3, SW4.2, SW12.2, SW13.2, SW26.2, SW27.2, SW39.2, SW40.2, SW53.2
C2: J2.18, J3.5, SW14.2, SW15.2, SW28.2, SW29.2, SW41.2, SW42.2, SW54.2, SW55.2
C3: J2.17, J3.7, SW16.2, SW17.2, SW30.2, SW31.2, SW43.2, SW44.2, SW56.2, SW57.2
C4: J2.16, J3.9, SW18.2, SW19.2, SW32.2, SW33.2, SW45.2, SW46.2, SW58.2, SW59.2
C5: J2.15, SW21.2, SW34.2, SW47.2, SW48.2, SW60.2, SW61.2, SW68.2, SW71.2
C6: J2.14, SW9.2, SW20.2, SW22.2, SW36.2, SW49.2, SW62.2, SW69.2, SW70.2
C7: J2.20, SW2.2, SW6.2, SW8.2, SW10.2, SW11.2, SW25.2, SW37.2, SW65.2
COM: J2.2, J4.1, SW38.2, SW51.2, SW52.2, SW63.2, SW64.2, SW66.2
GND: D1.1 (K), J2.1, J4.2
unnamed: D1.2 (A), R1.2
POWER: J2.3, SW67.2
R0: J2.12, SW10.1, SW12.1, SW14.1, SW16.1, SW18.1, SW23.1, SW69.1, SW71.1
R1: J2.11, SW26.1, SW28.1, SW30.1, SW32.1, SW34.1, SW36.1, SW37.1, SW50.1
R2: J2.10, SW2.1, SW24.1, SW39.1, SW41.1, SW43.1, SW45.1, SW47.1, SW49.1
R3: J2.5, SW7.1, SW11.1, SW13.1, SW15.1, SW17.1, SW19.1, SW68.1, SW70.1
R4: J2.8, SW1.1, SW9.1, SW53.1, SW55.1, SW57.1, SW59.1, SW61.1, SW65.1
R5: J2.7, SW3.1, SW8.1, SW22.1, SW40.1, SW42.1, SW44.1, SW46.1, SW48.1
R6: J2.6, SW5.1, SW20.1, SW21.1, SW25.1, SW27.1, SW29.1, SW31.1, SW33.1
R7: J2.9, SW4.1, SW6.1, SW35.1, SW54.1, SW56.1, SW58.1, SW60.1, SW62.1
VBATT: J2.4, SW67.1
X0: J2.25, J3.2, SW38.1
X1: J2.24, J3.4, SW64.1
X2: J2.23, J3.6, SW51.1
X3: J2.22, J3.8, SW52.1, SW63.1
X4: J2.21, J3.10, SW66.1

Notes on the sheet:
Locking MX switches are hard to get, but If you have one it can be used.
Sparebar on original is 8U, but that size is not available, so we use 6U. We add an extra 1U to either side.
1.75U
Optional: Requires +5V on pin 26
2.25U
POWER LED
1.5U
Matrix Link: Used to connect the Xn keys to the MAIN matrix when used on single matrix systems. Creates 8x9 Matrix. * For std CLCD keyboard, Jumper J4 only. * For 8x9 matrix, jumper J3 only.
Commodore LCD prototype (aka "CLCD") MX Keyboard - This keyboard is different from other CBM keyboards in that the special control keys are not part of the main matrix, but are decoded separately. Changes from real CLCD Keyboard: - 6U spacebar with stabilizers. - Inverted T cursor keys using MX swi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
CONNECTOR
CLCD-V2-R1 (Inverted T Cursor)
1.25U
CAPS-LOCK
JUMPERS
+5V Added for optional power LED.
SPACEBAR
DESCRIPTION
Updated: 2022-06-01
CLCD KEYBOARD

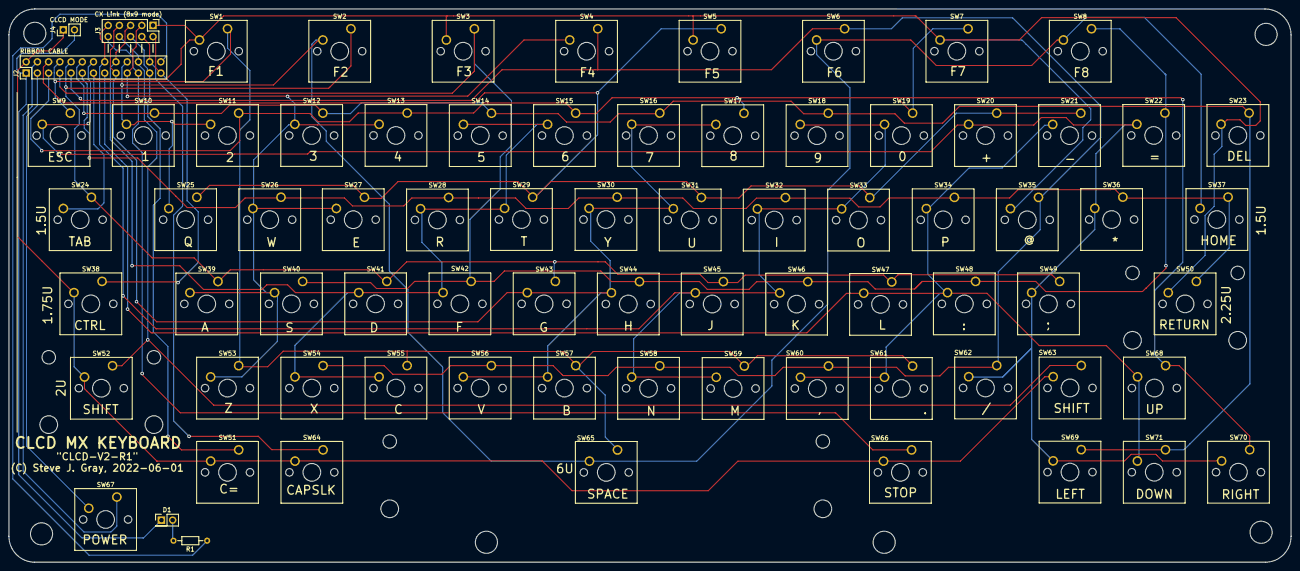
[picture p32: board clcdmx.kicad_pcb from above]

Board: 2 copper layers, 290.1 x 125.2 mm, 76 parts (0 on the bottom side), 27 nets.

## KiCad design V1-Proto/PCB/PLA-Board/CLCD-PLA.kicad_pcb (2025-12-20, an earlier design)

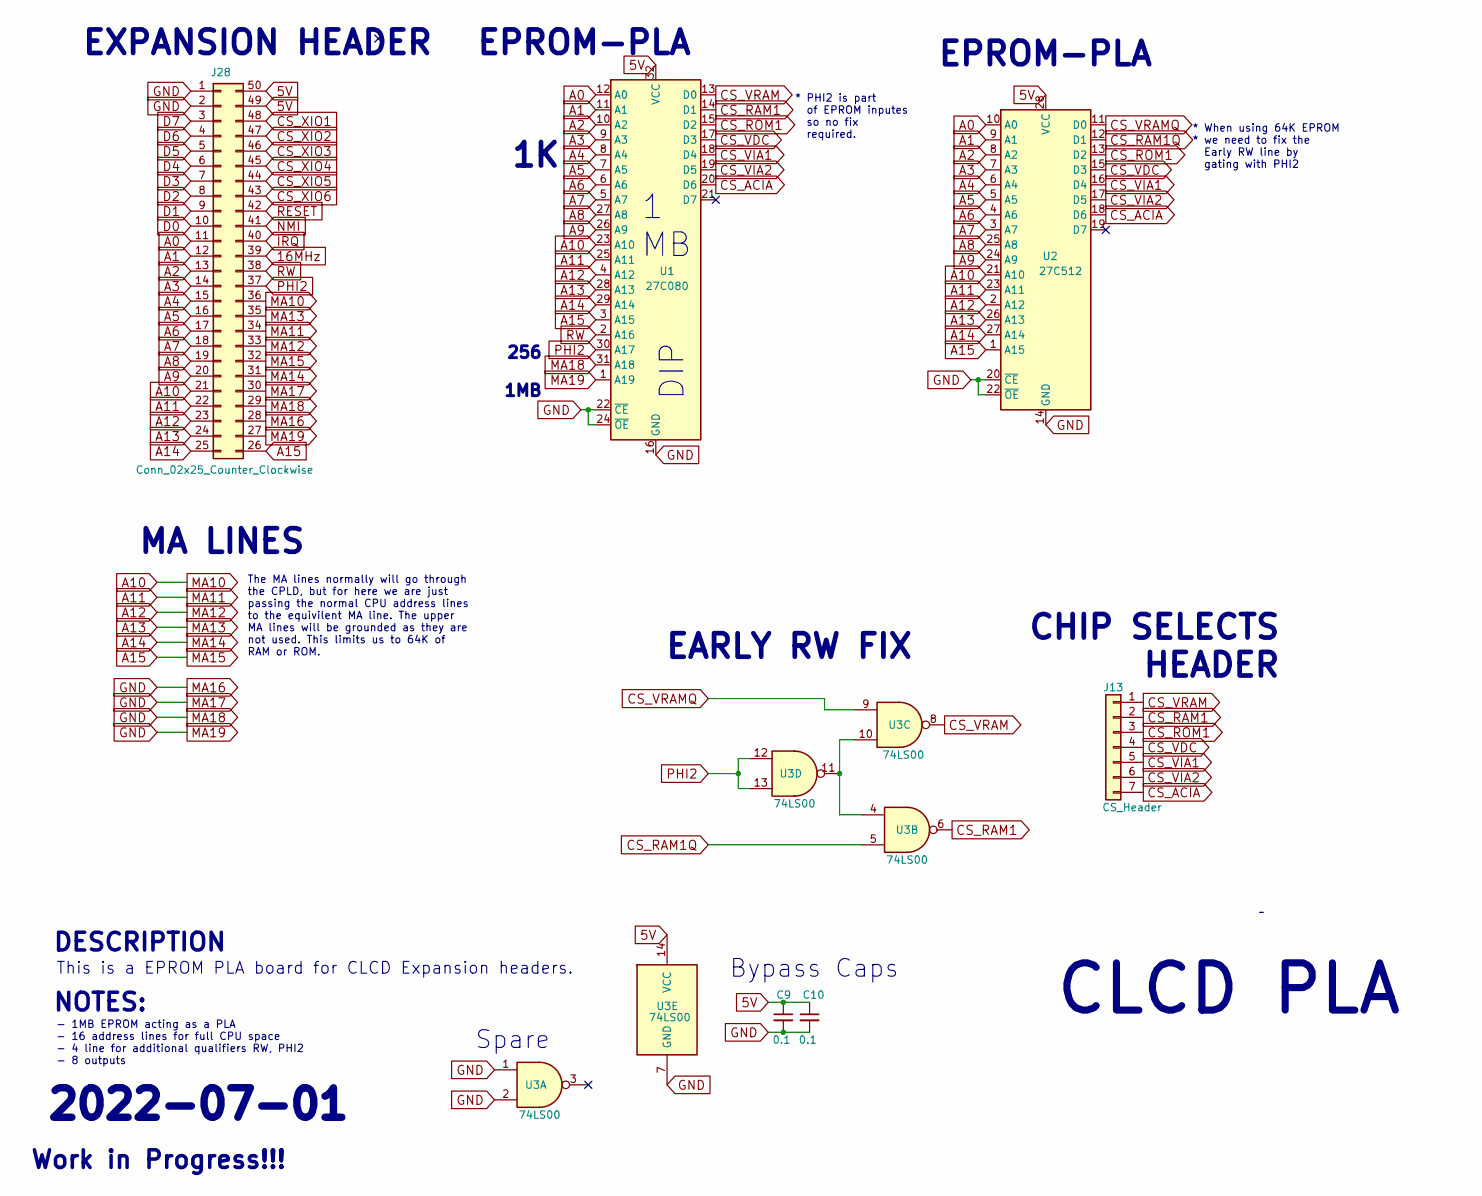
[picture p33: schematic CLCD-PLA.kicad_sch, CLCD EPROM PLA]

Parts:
C9, C10: 0.1; C_Disc_D4.7mm_W2.5mm_P5.00mm
J13: CS_Header; PinHeader_1x07_P2.54mm_Vertical
J28: Conn_02x25_Counter_Clockwise; PinHeader_2x25_P2.54mm_Vertical
U1: 27C080; DIP-32_W15.24mm_LongPads
U2: 27C512; DIP-28_W15.24mm
U3: 74LS00; DIP-14_W7.62mm_LongPads

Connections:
5V: C9.1, C10.1, J28.49, J28.50, U1.32 (VCC), U2.28 (VCC), U3.14 (VCC)
16MHz: J28.39
A0: J28.11, U1.12 (A0), U2.10 (A0)
A1: J28.12, U1.11 (A1), U2.9 (A1)
A2: J28.13, U1.10 (A2), U2.8 (A2)
A3: J28.14, U1.9 (A3), U2.7 (A3)
A4: J28.15, U1.8 (A4), U2.6 (A4)
A5: J28.16, U1.7 (A5), U2.5 (A5)
A6: J28.17, U1.6 (A6), U2.4 (A6)
A7: J28.18, U1.5 (A7), U2.3 (A7)
A8: J28.19, U1.27 (A8), U2.25 (A8)
A9: J28.20, U1.26 (A9), U2.24 (A9)
A10: J28.21, J28.36, U1.23 (A10), U2.21 (A10)
A11: J28.22, J28.34, U1.25 (A11), U2.23 (A11)
A12: J28.23, J28.33, U1.4 (A12), U2.2 (A12)
A13: J28.24, J28.35, U1.28 (A13), U2.26 (A13)
A14: J28.25, J28.31, U1.29 (A14), U2.27 (A14)
A15: J28.26, J28.32, U1.3 (A15), U2.1 (A15)
CS_ACIA: J13.7, U1.20 (D6), U2.18 (D6)
CS_RAM1: J13.2, U1.14 (D1), U3.6
CS_RAM1Q: U2.12 (D1), U3.5
CS_ROM1: J13.3, U1.15 (D2), U2.13 (D2)
CS_VDC: J13.4, U1.17 (D3), U2.15 (D3)
CS_VIA1: J13.5, U1.18 (D4), U2.16 (D4)
CS_VIA2: J13.6, U1.19 (D5), U2.17 (D5)
CS_VRAM: J13.1, U1.13 (D0), U3.8
CS_VRAMQ: U2.11 (D0), U3.9
CS_XIO1: J28.48
CS_XIO2: J28.47
CS_XIO3: J28.46
CS_XIO4: J28.45
CS_XIO5: J28.44
CS_XIO6: J28.43
D0: J28.10
D1: J28.9
D2: J28.8
D3: J28.7
D4: J28.6
D5: J28.5
D6: J28.4
D7: J28.3
GND: C9.2, C10.2, J28.1, J28.2, J28.27, J28.28, J28.29, J28.30, U1.1 (A19), U1.16 (GND), U1.22 (~CE), U1.24 (~OE), U1.31 (A18), U2.14 (GND), U2.20 (~CE), U2.22 (~OE), U3.1, U3.2, U3.7 (GND)
unnamed: U3.4, U3.10, U3.11
PHI2: J28.37, U1.30 (A17), U3.12, U3.13
RESET: J28.42
RW: J28.38, U1.2 (A16)
~IRQ: J28.40
~NMI: J28.41

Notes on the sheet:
DESCRIPTION
CHIP SELECTS HEADER
EPROM-PLA
Work in Progress!!!
The MA lines normally will go through the CPLD, but for here we are just passing the normal CPU address lines to the equivilent MA line. The upper MA lines will be grounded as they are not used. This limits us to 64K of RAM or ROM.
NOTES:
This is a EPROM PLA board for CLCD Expansion headers.
Spare
Bypass Caps
2022-07-01
EARLY RW FIX
* When using 64K EPROM * we need to fix the Early RW line by gating with PHI2
1 MB
MA LINES
* PHI2 is part of EPROM inputes so no fix required.
CLCD PLA
256 1MB
- 1MB EPROM acting as a PLA - 16 address lines for full CPU space - 4 line for additional qualifiers RW, PHI2 - 8 outputs
DIP
EXPANSION HEADER

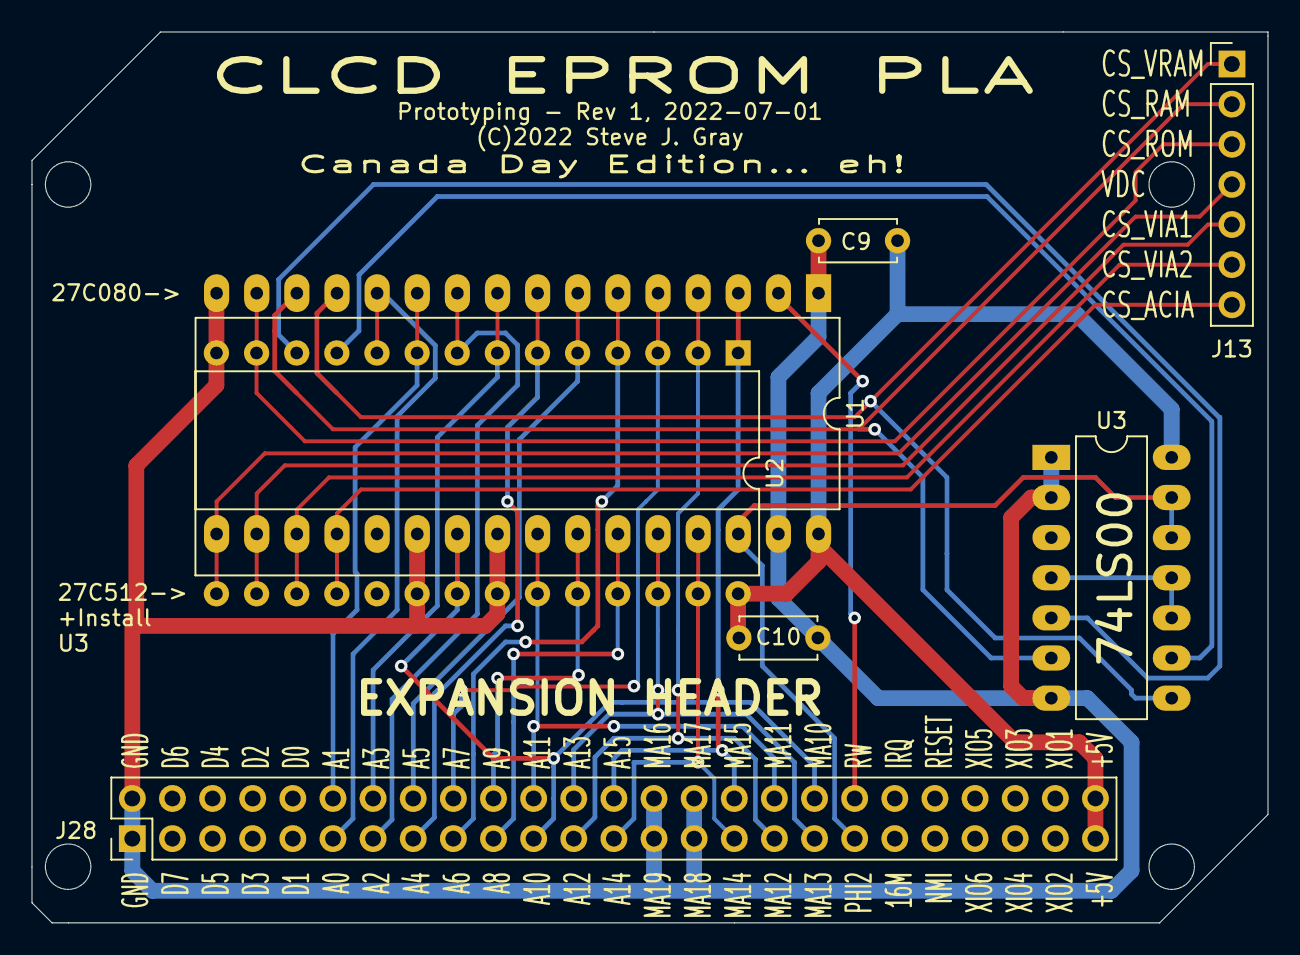
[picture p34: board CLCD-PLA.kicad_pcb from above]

Board: 2 copper layers, 78.2 x 56.4 mm, 7 parts (0 on the bottom side), 30 nets.

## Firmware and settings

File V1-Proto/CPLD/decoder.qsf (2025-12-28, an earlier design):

# -------------------------------------------------------------------------- #
#
# Copyright (C) 1991-2013 Altera Corporation
# Your use of Altera Corporation's design tools, logic functions 
# and other software and tools, and its AMPP partner logic 
# functions, and any output files from any of the foregoing 
# (including device programming or simulation files), and any 
# associated documentation or information are expressly subject 
# to the terms and conditions of the Altera Program License 
# Subscription Agreement, Altera MegaCore Function License 
# Agreement, or other applicable license agreement, including, 
# without limitation, that your use is for the sole purpose of 
# programming logic devices manufactured by Altera and sold by 
# Altera or its authorized distributors.  Please refer to the 
# applicable agreement for further details.
#
# -------------------------------------------------------------------------- #
#
# Quartus II 64-Bit
# Version 13.0.1 Build 232 06/12/2013 Service Pack 1 SJ Web Edition
# Date created = 16:04:12  January 04, 2023
#
# -------------------------------------------------------------------------- #
#
# Notes:
#
# 1) The default values for assignments are stored in the file:
#		decoder_assignment_defaults.qdf
#    If this file doesn't exist, see file:
#		assignment_defaults.qdf
#
# 2) Altera recommends that you do not modify this file. This
#    file is updated automatically by the Quartus II software
#    and any changes you make may be lost or overwritten.
#
# -------------------------------------------------------------------------- #


set_global_assignment -name FAMILY MAX7000S
set_global_assignment -name DEVICE "EPM7128SLC84-15"
set_global_assignment -name TOP_LEVEL_ENTITY decoder
set_global_assignment -name ORIGINAL_QUARTUS_VERSION "13.0 SP1"
set_global_assignment -name PROJECT_CREATION_TIME_DATE "16:04:12  JANUARY 04, 2023"
set_global_assignment -name LAST_QUARTUS_VERSION "13.0 SP1"
set_global_assignment -name PROJECT_OUTPUT_DIRECTORY output_files
set_global_assignment -name ERROR_CHECK_FREQUENCY_DIVISOR "-1"
set_global_assignment -name EDA_SIMULATION_TOOL "ModelSim-Altera (VHDL)"
set_global_assignment -name EDA_OUTPUT_DATA_FORMAT VHDL -section_id eda_simulation
set_global_assignment -name MAX7000_DEVICE_IO_STANDARD TTL
set_location_assignment PIN_2 -to phi2
set_location_assignment PIN_1 -to resetb
set_location_assignment PIN_83 -to osc
set_location_assignment PIN_4 -to cs_vramb
set_location_assignment PIN_5 -to cs_ram1b
set_location_assignment PIN_6 -to cs_rom1b
set_location_assignment PIN_8 -to cs_vdcb
set_location_assignment PIN_9 -to cs_via1b
set_location_assignment PIN_10 -to cs_via2b
set_location_assignment PIN_12 -to cpu_clk
set_location_assignment PIN_15 -to vdc_dclk
set_location_assignment PIN_17 -to vdc_fontopt
set_location_assignment PIN_16 -to vdc_romram
set_location_assignment PIN_73 -to d[0]
set_location_assignment PIN_74 -to d[1]
set_location_assignment PIN_75 -to d[2]
set_location_assignment PIN_76 -to d[3]
set_location_assignment PIN_77 -to d[4]
set_location_assignment PIN_79 -to d[5]
set_location_assignment PIN_80 -to d[6]
set_location_assignment PIN_81 -to d[7]
set_location_assignment PIN_30 -to ma[10]
set_location_assignment PIN_28 -to ma[11]
set_location_assignment PIN_27 -to ma[12]
set_location_assignment PIN_29 -to ma[13]
set_location_assignment PIN_24 -to ma[14]
set_location_assignment PIN_25 -to ma[15]
set_location_assignment PIN_20 -to ma[16]
set_location_assignment PIN_22 -to ma[17]
set_location_assignment PIN_21 -to ma[18]
set_location_assignment PIN_18 -to ma[19]
set_location_assignment PIN_51 -to a[0]
set_location_assignment PIN_52 -to a[1]
set_location_assignment PIN_54 -to a[2]
set_location_assignment PIN_55 -to a[3]
set_location_assignment PIN_56 -to a[4]
set_location_assignment PIN_57 -to a[5]
set_location_assignment PIN_58 -to a[6]
set_location_assignment PIN_60 -to a[7]
set_location_assignment PIN_61 -to a[8]
set_location_assignment PIN_63 -to a[9]
set_location_assignment PIN_64 -to a[10]
set_location_assignment PIN_65 -to a[11]
set_location_assignment PIN_67 -to a[12]
set_location_assignment PIN_68 -to a[13]
set_location_assignment PIN_69 -to a[14]
set_location_assignment PIN_70 -to a[15]
set_location_assignment PIN_39 -to j2[0]
set_location_assignment PIN_40 -to j2[1]
set_location_assignment PIN_41 -to j2[2]
set_location_assignment PIN_44 -to j2[3]
set_location_assignment PIN_45 -to j2[4]
set_location_assignment PIN_46 -to j2[5]
set_location_assignment PIN_48 -to j2[6]
set_location_assignment PIN_49 -to j2[7]
set_location_assignment PIN_50 -to rwb
set_location_assignment PIN_11 -to cs_aciab
set_global_assignment -name OPTIMIZE_HOLD_TIMING OFF
set_global_assignment -name OPTIMIZE_MULTI_CORNER_TIMING OFF
set_global_assignment -name FITTER_EFFORT "STANDARD FIT"
set_global_assignment -name SDC_FILE decoder.sdc
set_global_assignment -name VHDL_FILE decoder_testbench.vhd
set_global_assignment -name VHDL_FILE decoder.vhd -hdl_version VHDL_2008
set_global_assignment -name CDF_FILE ../output_files/Chain5.cdf

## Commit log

2025-12-20 My Commodore LCD Re-creation Project
    Initial release - Complete V1 project files. V2 work-in-progress PCB.
    [CLCD-PLA.kicad_pcb, CLCD-PLA.kicad_sch, CLCD-VDC-BOM.csv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]
2025-12-22 Add some pics of V1
    Add some pics of pcb development, case and design, keyboard, etc.
2025-12-27 fix testbench, new readme, and new timing constraints
    [decoder.qsf]
2025-12-28 Add Sketchup files
    Add Sketchup files for Case in folder. Moved STL files to folder. Update Readme.
    [Full model.skp, batterycover-rev3.skp, batterycover-rev4.skp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]
2026-08-18 Add Full V1 case sketchup file
    This is the complete case assembled into one sketchup file.
    [CLCD-case-rev1 full.skp]

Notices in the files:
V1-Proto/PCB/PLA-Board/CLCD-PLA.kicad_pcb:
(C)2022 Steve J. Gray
